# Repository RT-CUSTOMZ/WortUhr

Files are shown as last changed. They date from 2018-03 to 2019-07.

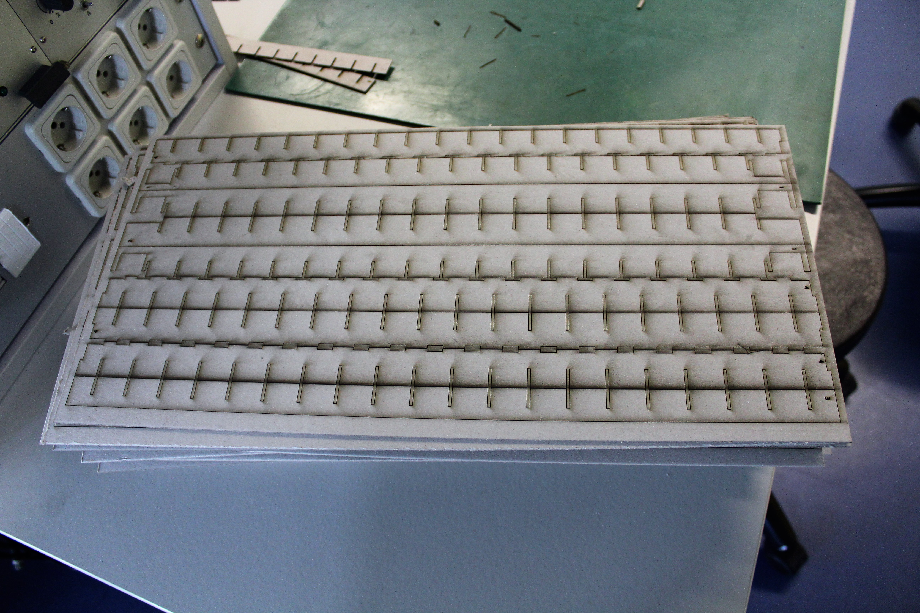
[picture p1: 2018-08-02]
Media/Gitterstreifen.jpg

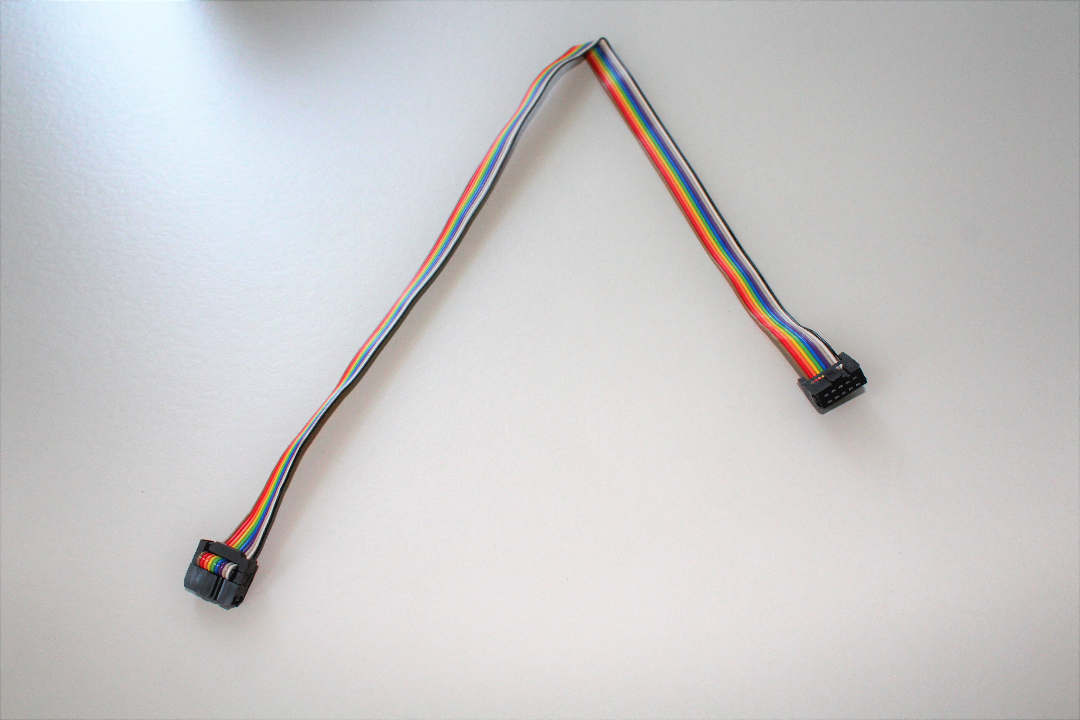
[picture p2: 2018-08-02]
Media/Flachbandkabel.jpg

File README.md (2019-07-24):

# Hardware
Im
Das Buchstabenlayout dieser WortUhr ist angelehnt an das Layout, welches von Frank Meyer verwendet wird.

# Software
Die Software von Frank Meyer wurde minimal angepasst. Das Layout der Matrix, sowie die Datenrichtung wurde angepasst.

Documentation: https://www.mikrocontroller.net/articles/WordClock_mit_WS2812

Version: 2.9.5

Copyright (c) 2014-2019 Frank Meyer - frank(at)fli4l.de

This program is free software; you can redistribute it and/or modify
it under the terms of the GNU General Public License as published by
the Free Software Foundation; either version 2 of the License, or
(at your option) any later version.

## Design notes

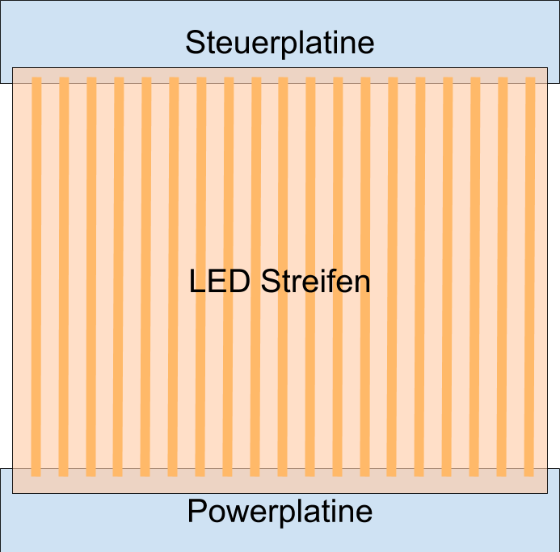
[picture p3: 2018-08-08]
Media/Struktur_Platinen.png

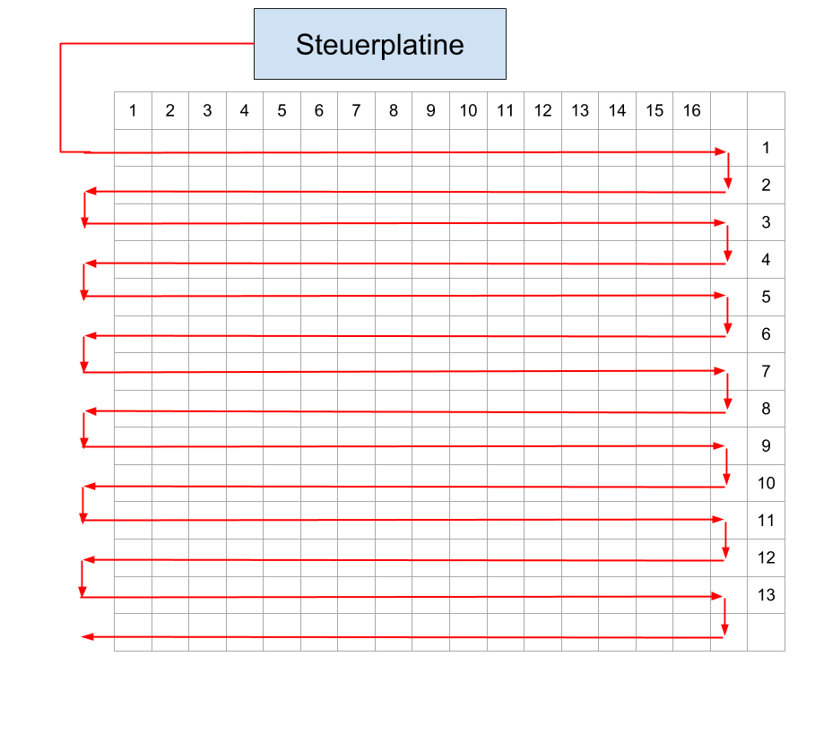
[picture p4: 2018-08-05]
Media/WortUhr alt.png

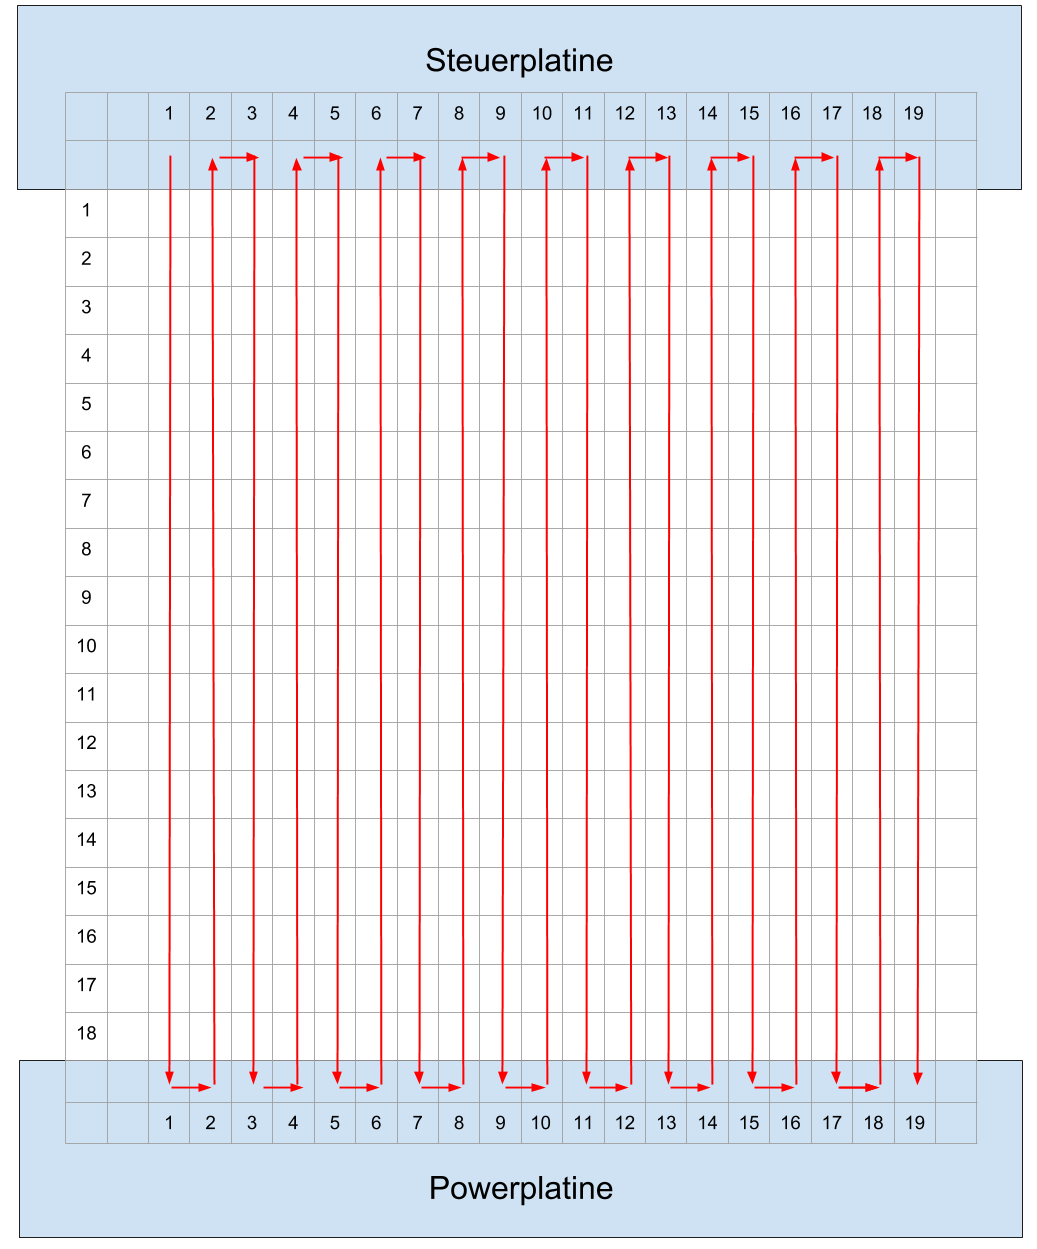
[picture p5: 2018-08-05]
Media/WortUhr neu.png

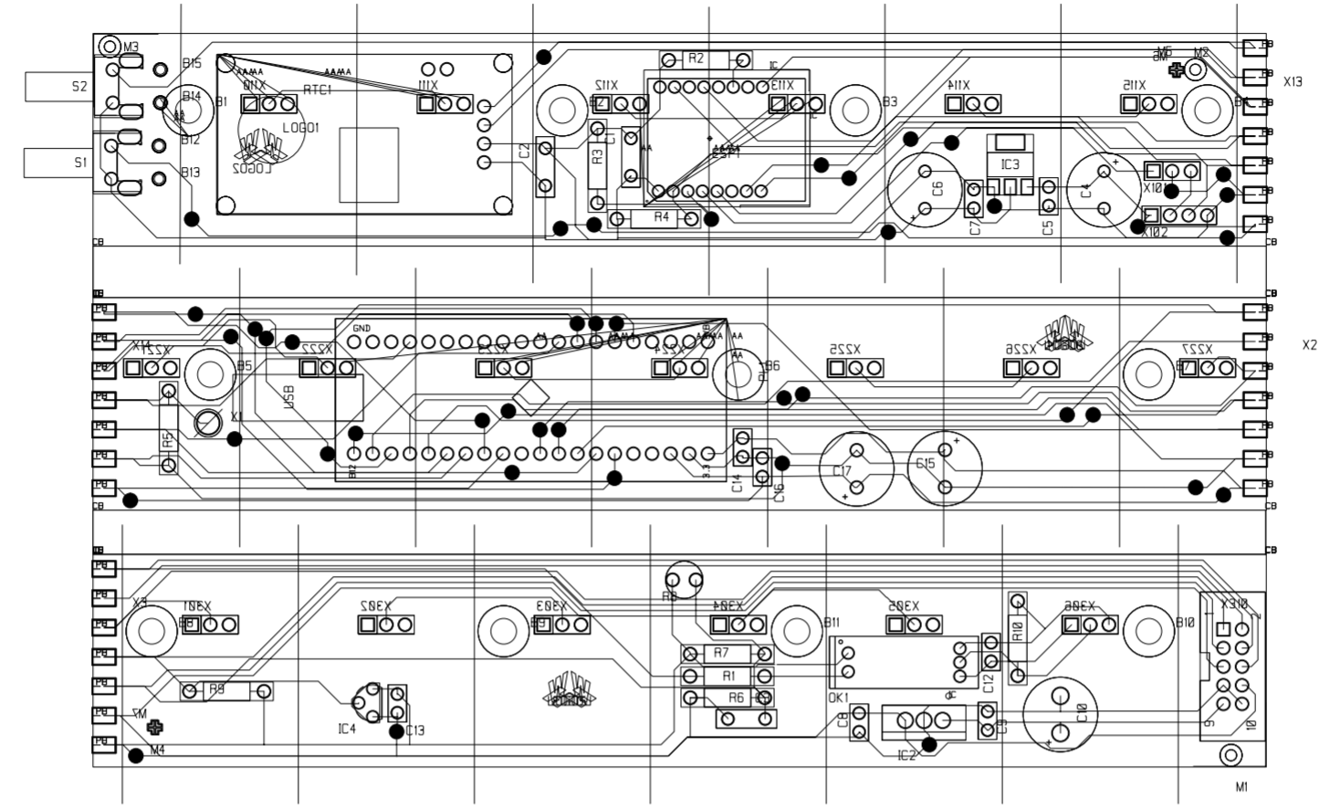
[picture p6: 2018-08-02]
Media/Steuerplatine - Viaplan.PNG

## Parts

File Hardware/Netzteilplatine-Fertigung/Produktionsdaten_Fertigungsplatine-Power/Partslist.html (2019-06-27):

CADSTAR Design Editor Version | 17.0.0.3
Design: | R:\Hardies\Wortuhr\Wortuhr_Netzteilplatine\Version V2.1\Fertigungsplatine_2.pcb
Design Title: | Wortuhr-Powerplatine_Version2.1-Kati
Date: | Donnerstag, 27. Juni 2019
Time: | 18:59
Part Name/Number | Description | Qty | Comps. | Part Acceptance
10_pol_wanne | Wannenstecker 10 pol | 1 | X101
4N36 | Optokoppler 2,5kV DIL6 7Âµs | 6 | OK11-12
 |  |  | OK21-22
 |  |  | OK31-32
Bohrung3_5 | Befestigungsbohrung 3,5mm | 10 | B1-10
ELKO_470µ_25V_RM5_RADIAL_D10MM | Elektrolytkondensator radial_D | 6 | C11-12
 |  |  | C21-22
 |  |  | C31-32
HEBW21 | HEBW21 | 1 | X102
IRF7425 | P-Kanal Mosfet | 3 | T11
 |  |  | T21
 |  |  | T31
LM2576 | LM2576 | 3 | IC1-3
LPKF_Passmarke | Platzhalter fuer Passmarke | 3 | M1-3
Loetoese | Lötöse | 3 | X1-3
PAD | Einzelnes Pad 1,5mm | 26 | X103-109
 |  |  | X203-209
 |  |  | X213-218
 |  |  | X313-318
PASTEN_PASSMARKE | Platzhalter fuer Passmarke | 4 | M4-7
Platzhalter | Platzhalter für Gehäuseauswahl | 1 | PCB1
RES_19K1_1.00%_0.40W_axial_Metallschicht_RT | Metallschichtwiderstand 19,1K | 6 | R15-16
 |  |  | R25-26
 |  |  | R35-36
RES_1K2_5.00%_0.25W_axial_Kohleschicht | Kohleschichtwiderstand 1,2k Oh | 3 | R11
 |  |  | R21
 |  |  | R31
RES_330R_5.00%_0.25W_AXIAL_KOHLESCHICHT_RT | Kohleschichtwiderstand 330 Ohm | 6 | R13-14
 |  |  | R23-24
 |  |  | R33-34
RES_3K9_5.00%_0.25W_axial_Kohleschicht | Kohleschichtwiderstand 3,9k Oh | 3 | R12
 |  |  | R22
 |  |  | R32
SPULE 100UH | Spule 100uH | 3 | L11
 |  |  | L21
 |  |  | L31
Steckerleiste_3pol | Steckerleiste SIL RM2,54 | 19 | X110-115
 |  |  | X221-227
 |  |  | X301-306
VS-30BQ100 | Schottky-Diode_SMD | 3 | D11
 |  |  | D21
 |  |  | D31
WHS_LOGO | Platzhalter für WHS Logo | 2 | LOGO1-2

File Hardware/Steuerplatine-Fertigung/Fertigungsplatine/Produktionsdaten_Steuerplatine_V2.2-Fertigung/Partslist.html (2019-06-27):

CADSTAR Design Editor Version | 17.0.0.3
Design: | R:\Hardies\Wortuhr\Wortuhr_Steuerplatine\Version 2.2\Fertigungsplatine\Fertigungsplatine_ Wortuhr_1.pcb
Design Title: | Wortuhr-Steuerplatine_Version_2.2-Kati
Date: | Donnerstag, 27. Juni 2019
Time: | 19:01
Part Name/Number | Description | Qty | Comps. | Part Acceptance
10_pol_wanne | Wannenstecker 10 pol | 1 | X31
7805_GESTEPPT | 7805_gesteppt | 1 | IC31
AMS1117 | Linearregler | 1 | IC10
Bohrung1_0 | Befestigungsbohrung 1,0mm | 4 | B13-16
Bohrung3_5 | Befestigungsbohrung 3,5mm | 8 | B1-8
CAP_100n_50V_RM5_L8mm_B2.5mm_Z5U_RT | Keramikkondensator L8mm_B2,5mm | 10 | C10-11
 |  |  | C13-14
 |  |  | C20-21
 |  |  | C30
 |  |  | C32-34
CAP_1n_50V_RM5_L4mm_B2mm_C0G_RT | Keramikkondensator L4mm_B2mm 1 | 3 | C22-23
 |  |  | C31
DS18B20 | Digital Thermometer, 1-wire | 1 | IC30
ELKO_10µ_63V_RM5_radial_D9mm | Elektrolytkondensator radial_D | 2 | C24-25
ELKO_330µ_35V_RM5_radial_D10mm | Elektrolytkondensator radial_D | 1 | C35
ELKO_47µ_63V_RM5_radial_D10mm | Elektrolytkondensator radial_D | 2 | C12
 |  |  | C15
ESP07 | ESP07 | 1 | ESP1
LDR | Fotowiderstand | 1 | R35
LPKF_Passmarke | Platzhalter fuer Passmarke | 4 | M1-2
 |  |  | M8-9
Loetoese | Lötöse | 3 | X10
 |  |  | X20
 |  |  | X30
PAD | Einzelnes Pad 1,5mm | 1 | X21
PASTEN_PASSMARKE | Platzhalter fuer Passmarke | 6 | M4-7
 |  |  | M10-11
RES_120R_5.00%_0.25W_axial_Kohleschicht_RT | Kohleschichtwiderstand 120 Ohm | 1 | R32
RES_240K_1.00%_0.40W_AXIAL_METALLSCHICHT_RT | Metallschichtwiderstand 240K O | 1 | R33
RES_4K53_1.00%_0.40W_axial_Metallschicht_RT | Metallschichtwiderstand 4,53K | 2 | R10-11
RES_8K2_5.00%_0.25W_axial_Kohleschicht_RT | Kohleschichtwiderstand 8,2k Oh | 5 | R12-14
 |  |  | R21
 |  |  | R30
RES_91R_1.00%_0.40W_axial_Metallschicht_RT | Metallschichtwiderstand 91 Ohm | 1 | R20
RES_nicht_bestückt_axial | Platzhalterwiderstand nicht be | 2 | R31
 |  |  | R34
RTC_DS3231_32K | RTC_DS3231_32K | 1 | RTC10
RT_LOGO | Platzhalter fuer RT Logo | 2 | LOGO7-8
SMD_STECKER_7_12 | SMD Loetbruecke | 2 | X14
 |  |  | X132
SMD_Stecker_7_23 | SMD Loetbruecke | 2 | X2-3
STM32-einfach | Tochterplatine STM32 | 1 | PL20
Steckerleiste_2pol | Steckerleiste SIL RM2,54 | 1 | X11
Steckerleiste_3pol | Steckerleiste SIL RM2,54 | 20 | X12
 |  |  | X110-115
 |  |  | X221-227
 |  |  | X301-306
Steckerleiste_4pol | Steckerleiste SIL RM2,54 | 1 | X13
TLP582 | Optokoppler 5kV Schmitt Trigge | 1 | OK31
Taster3305 | Kurzhubtaster PHAP3305D | 2 | S10-11
WHS_LOGO | Platzhalter für WHS Logo | 4 | LOGO3-6

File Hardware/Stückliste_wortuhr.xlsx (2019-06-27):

Stk.: | Bezeichnung: | Firma: | Best. Nr.: | Seite: | Netto: | Brutto: | Rabatt: | Preis/Stk: | Gesamt: | Arbeitsschritt | Bauteilbezeichnung: | Bestand:
Steuerplatine
1 | RES_120R_5.00%_0.25W_axial_Kohleschicht_RT |  |  |  | 0.00 € | 0.00 € |  | 0.00 € | 0.00 € | 1 | R32 | RT
5 | RES_8K2_5.00%_0.25W_axial_Kohleschicht_RT |  |  |  | 0.00 € | 0.00 € |  | 0.00 € | 0.00 € | 2 | R12-14, R21, R30 | RT
2 | 4K53Ohm |  |  |  |  |  |  |  |  | 3 | R10-11 | RT
1 | 100Ohm |  |  |  |  |  |  |  |  | 4 | R20
1 | RES_240K_1.00%_0.40W_AXIAL_METALLSCHICHT_RT |  |  |  | 0.00 € | 0.00 € |  | 0.00 € | 0.00 € | 5 | R33 | RT
1 | AMS1117-Linearregler | reichelt | LM 1117 MP5,0 |  | 0.72 € | 0.86 € |  | 0.86 € | 0.86 € | 6 | IC10 | 57
1 | 2pol Steckerleiste RM2.54 | reichelt | SL1X36G2,54 |  | 0.14 € | 0.17 € |  | 0.17 € | 0.17 € | 7
1 | 3pol Stiftleiste Rm2,54 | reichelt | SL1X36G2,54 |  | 0.14 € | 0.17 € |  | 0.17 € | 0.17 € | 8 | X12 | 36pol:56
2 | 4pol Stiftleiste RM2,54 | reichelt | SL1X36G2,54 |  | 0.14 € | 0.17 € |  | 0.17 € | 0.34 € | 9 | X13, RTC | s.o.
2 | 8pol Stiftleiste RM2 | reichelt | SL1X32G2,00 |  | 0.21 € | 0.25 € |  | 0.25 € | 0.50 € | 10 | ESP | 32pol:37
10 | CAP_100n_50V_RM5_L8mm_B2.5mm_X7R | reichelt | C3X7R 100NB50 |  | 0.08 € | 0.10 € |  | 0.10 € | 1.00 € | 11 | C10-11, C13-14, C20-21, C30, C32-34 | 12
3 | CAP_1n_50V_RM5_L4mm_B2mm_C0G_RT |  |  |  | 0.00 € | 0.00 € |  | 0.00 € | 0.00 € | 12 | C22-23, C31 | RT
1 | Temperatursensor | reichelt | DS18B20 |  | 1.51 € | 1.80 € |  | 1.80 € | 1.80 € | 13 | IC30 | 11
1 | LDR | RS | 914-6710 |  | 0.71 € | 0.84 € |  | 0.84 € | 0.84 € | 14 | R35 | 46
2 | Taster 3301D | reichelt | TASTER 3301D |  | 0.11 € | 0.13 € |  | 0.13 € | 0.26 € | 15 | S10-11 | 8
1 | 7805 Spannungsregler 5V TO220 gesteppt | reichelt | R-78 E50-05 |  | 2.77 € | 3.30 € |  | 3.30 € | 3.30 € | 16 | IC31 | 3
1 | TLP582 Optokoppler 5kV Schmitt Trigge_RT |  |  |  | 0.00 € | 0.00 € |  | 0.00 € | 0.00 € | 17 | OK31 | RT
2 | ELKO_47µ_63V_RM5_radial_D10mm | RS | 771-1586 |  | 0.08 € | 0.09 € |  | 0.09 € | 0.19 € | 18 | C24-25 | 39
1 | ELKO_330µ_35V_RM5_radial_D10mm | reichelt | RAD 330/35 |  | 0.07 € | 0.08 € |  | 0.08 € | 0.08 € | 19 | C35 | 18
2 | ELKO_10µ_63V_RM5_radial_D9mm | reichelt | RAD 10/63 |  | 0.02 € | 0.02 € |  | 0.02 € | 0.04 € | 20 | C12, C15 | 38
1 | 10_pol_wanne | reichelt | WSL 10G |  | 0.08 € | 0.10 € |  | 0.10 € | 0.10 € | 21 | X31 | 4
 |  |  |  |  |  | 0.00 € |  | 0.00 €
 |  |  |  |  |  | 0.00 € |  | 0.00 €
1 | RTC_DS3231 | eckstein | CP14004 |  | 0.00 € | 3.86 |  | 3.86 € | 3.86 € | 22 | RTC1 | 36
2 | M2 Schrauben 16mm | reichelt | SZK M2X16-200 |  | 1.85 € | 2.20 € |  | 2.20 € | 4.40 € | 23 | M2 Schrauben | 200
2 | M2 Muttern | reichelt | SK M2-1000 |  | 9.20 € | 10.95 € |  | 10.95 € | 21.90 € | 24 | M2 Muttern | 45
2 | Abstandsbolzen |  |  |  | 0.00 € | 0.00 € |  | 0.00 € | 0.00 € | 25 |  | 100
1 | ESP07 | wetterott | 20150271 |  | 0.00 € | 3.85 € |  | 3.85 € | 3.85 € | 26 | ESP1 | 29
2 | Sockelleisten 1X32 RM 2 | reichelt | BL1X32G 2,00 |  | 0.68 € | 0.81 € |  | 0.81 € | 1.62 € | 27 | 8pol RM2 | 11
1 | STM32 F103C8T6 | ebay |  |  | 0.00 € | 4.49 € |  | 4.49 € | 4.49 € | 28 | PL1 | 0
2 | Sockelleisten 1x20 RM2,54 | reichelt | BL 1X20G 2,54 |  | 0.61 € | 0.73 € |  | 0.73 € | 1.45 € | 29 | 20pol RM2,54 | 100
19 | gewinkelte Steckerleiste3 pol RM2,54 |  | BL 1X20W8 2,54 |  | 0.38 € | 0.45 € |  | 0.45 € | 8.59 € | 30 | X110-115, X221-227;x301-306 | 53
3 | Lötöse |  |  |  |  | 0.00 € |  | 0.00 € | 0.00 € | 40 | X10, X20, X30
 |  |  |  |  |  | 0.00 € |  | 0.00 € | 0.00 €
Zubehör |  |  |  |  |  | 0.00 € |  | 0.00 €
2 | 10 pol Pfostenbuchse | reichelt | PFL 10 |  | 0.08 € | 0.10 € |  | 0.10 € | 0.20 € |  |  | 1
1 | Flachbandkabel | reichelt | AWG28-10F 3M |  | 1.67 € | 1.99 € |  | 1.99 € | 1.99 €
342 | LED´s |  |  |  |  | 0.00 € |  | 0.00 € | 0.00 € |  |  | 4,75 Rollen |  | 11 Rollen
0,25 Rollen | Silberdrath | Bürklin | 90F272 |  | 37.60 € | 44.74 € |  | 44.74 € | #VALUE! |  |  | 5 mit CUBE! |  | n
1 | Bilderrahmen | Ikea | 003.784.36 |  |  | 12.99 € |  |  |  |  |  | 9 | 12
1 | Folie
24 | M3 Schrauben |  |  |  |  | 0.00 € |  | 0.00 € | 0.00 €
24 | M3 Muttern
24 | M3 Unterlegschreiben |  |  |  |  |  |  |  |  |  |  |  | 500
5cm | schrumpfschlauch 1,6mm |  |  |  |  |  |  |  |  | 14
Powerplatine |  |  |  |  |  | 0.00 € |  | 0.00 €
 |  |  |  |  |  | 0.00 € |  | 0.00 € | 0.00 €
19 | gewinkelte Steckerleiste3 pol RM2,54 |  | BL 1X20W8 2,54 |  | 0.38 € | 0.45 € |  | 0.45 € | 8.59 € | 41 | X110-115, C221-227, X301-306
12 | Sockelleisten 3pol RM2,54 |  |  |  |  | 0.00 € |  | 0.00 € | 0.00 € | 42 | OK11-12, OK21-22, OK31-32
3 | P-Ch FET IRF7425 | reichelt | IRF7425 |  | 0.78 | 0.93 € |  | 0.93 € | 2.78 € | 43 | T11, T21, T31
6 | Widerstand 19,1K RT |  |  |  |  | 0.00 € |  | 0.00 € | 0.00 € | 44 | R15-16, R25-26, R36-36 | RT
3 | Widerstand 1,2K | aliexpress |  |  |  |  |  | 0.00 € | 0.00 € | 45 | R11, R21, R31
6 | Widerstand 330R RT |  |  |  |  | 0.00 € |  | 0.00 € | 0.00 € | 46 | R13-14, R23-24, R33-34 | RT
3 | Widerstand 3,9K | aliexpress |  |  |  | 0.00 € |  | 0.00 € | 0.00 € | 47 | R12, R22, R32
3 | SMD Diode Shottky: VS-30BQ100 | farnell | 2628291 |  |  | 0.00 € |  | 0.00 € | 0.00 € | 48 | D11, D21, D31
3 | LM2576 S-ADJ | reichelt | LM 2576 S-ADJ |  | 1.51 | 1.80 € |  | 1.80 € | 5.39 € | 49 | IC1-3
3 | Spule 100uH | reichelt | L-PISR 100µ |  | 0.75 | 0.89 € |  | 0.89 € | 2.68 € | 50 | L11, L21, L31
1 | Wannenstecker 10Pol | reichelt | WSL 10G |  | 0.08 € | 0.10 € |  | 0.10 € | 0.10 € | 51 | X101
6 | Elko 470uF 25V | aliexpress |  |  |  | 0.00 € |  | 0.00 € | 0.00 € | 52 | C11-12, C21-22, C31-32
1 | Holsteckerbuchse | reichelt | LUM NEB 21R |  | 0.40 € | 0.48 € |  | 0.48 € | 0.48 € | 53 | X102
6 | Optokoppler 4N36 | reichelt | 4N36 |  | 0.22 | 0.26 € |  | 0.26 € | 1.57 € | 54 | OK11-12, OK21-22, OK31-32
3 | Lötöse |  |  |  |  |  |  |  |  | 55 | X1-3
 |  |  |  |  |  |  |  |  | #VALUE!

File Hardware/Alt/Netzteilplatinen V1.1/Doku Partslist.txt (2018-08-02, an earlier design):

<!DOCTYPE HTML PUBLIC "-//W3C//DTD HTML 4.01 Transitional//EN" "http://www.w3.org/TR/html4/loose.dtd"><HTML>
<HEAD>
<META NAME="GENERATOR" CONTENT="Cadstar Active Report">
<META NAME="AUTHOR" CONTENT="Zuken Ltd">
<TITLE>Parts List</TITLE>
<style type="text/css">/* CADSTAR HTML Reports CSS File V1.2 SL 08-Jul-2015 */

body
{
	font-family:'Lucida Sans Unicode', 'Lucida Grande', Sans-Serif;
	font-size:x-small;
	background:#FFF;
	color:#101010;
	margin-left:22px;
}

pre
{
    font-family:'Lucida Sans Unicode', 'Lucida Grande', Sans-Serif;
	font-size:x-small
} 

hr
{
	margin-right:22px;
    height:1px;
} 

td.number-col
{
	text-align:right
} 

ul
{
	margin-left:3em;
	padding-left:0;
} 

li
{	
	line-height:1.8em
} 

.label-for-check
{
	text-decoration:underline
}

.check-with-label:checked + .label-for-check
{
	color:#F01010
} 

a
{
	color:#000
} 

.hor-header-summary-a
{
    font-family:'Lucida Sans Unicode', 'Lucida Grande', Sans-Serif;
	font-size:1em;
    background:#FFF;
	margin-bottom:2em;
	margin-top:1em
} 

.hor-header-summary-a th
{
	font-size:14px;
	font-weight:400;
	border-bottom:2px solid #6678b1;
	padding:10px 24px
} 

.hor-header-summary-a td
{
	color:#101010;
	vertical-align:baseline;
	padding:9px 24px 0 0
}

.hor-header-summary-a tbody td
{
	color:#101010
} 

#content tr:hover 
{
    background: #FAFAFA;
} 

.hor-minimalist-a
{
    font-family:'Lucida Sans Unicode', 'Lucida Grande', Sans-Serif;
	font-size:x-small;
	background:#fff;
	margin-bottom:3em;
	#margin-top:3em;
	border-collapse:collapse;
	text-align:left;
	line-height:1em
}

.hor-minimalist-a td
{
	padding:9px 48px 0 0
} 

table
{
	margin-top:0;padding-top:0
} 

h1,h2,h3
{
	margin-bottom:0;
	padding-bottom:0
} 

h1
{
	font-size:1.5em
} 

h3,h4
{
	font-size:1.2em
} 

.hor-header-summary-a thead,.hor-minimalist-a thead
{
	color:#101010;
	font-weight:700;
	padding:10px 24px
} 

.ActiveLink 
{
	color:#000000
} 

.ActiveLinkDRC 
{
	color:#0000FF
} 

.ActiveLinkSelected 
{
	color:#000000; 
	background-color:#B0ffB0;
} 

.ActiveLinkDRCSelected 
{
	color:#0000FF; 
	background-color:#B0ffB0;
} 

pre
{
	display: inline
}

.altTable 
{
	font-size:1em;
	margin-bottom:2em;
	margin-top:1em;
	border-collapse:
	collapse;text-align:left
}

.altTable th
{
	font-size:14px;
	font-weight:500;
	border-bottom:2px;
	padding:2px 5px 5px
} 

.altTable td
{
	color:#101010;
	vertical-align:top;
	padding:1px 6px
}
</style>
</HEAD>
<body>
<H1>
Parts List
</H1>
<table class="hor-header-summary-a">
<tr><td>CADSTAR Design Editor Version</td><td>17.0.0.3</td></tr>
<tr><td>Design:</td><td>R:\TEMP\Wortuhr-Netzteilplatine -Nutzen 1,1-BO.pcb</td></tr>

<tr>

<td>
Design Title:
</td>

<td>
<pre>
WortUhr Powerplatine Nutzen</pre>

</td>

</tr>
<tr><td>Date:</td><td>Samstag, 28. Juli 2018</td></tr>
<tr><td>Time:</td><td>14:34</td></tr>

</table>
<hr>
<div id="content"><table class="hor-header-summary-a">

<thead>

<tr>

<td>
Part Name/Number       
</td>

<td>
Description
</td>

<td>
Qty
</td>

<td>
   Comps.
</td>

<td>
Part Acceptance
</td>

</tr>

</thead>

<tr>

<td>
10_pol_wanne
</td>

<td>
Wannenstecker 10 pol
</td>

<td class="number-col">
1
</td>

<td>
X101
</td>

</tr>

<tr>

<td>
1N5408
</td>

<td>
Silizium Diode
</td>

<td class="number-col">
3
</td>

<td>
D11
</td>

</tr>

<tr>

<td>

</td>

<td>

</td>

<td>

</td>

<td>
D21
</td>

</tr>

<tr>

<td>

</td>

<td>

</td>

<td>

</td>

<td>
D31
</td>

</tr>

<tr>

<td>
4N36
</td>

<td>
Optokoppler 2,5kV DIL6 7Âµs
</td>

<td class="number-col">
6
</td>

<td>
OK11-12
</td>

</tr>

<tr>

<td>

</td>

<td>

</td>

<td>

</td>

<td>
OK21-22
</td>

</tr>

<tr>

<td>

</td>

<td>

</td>

<td>

</td>

<td>
OK31-32
</td>

</tr>

<tr>

<td>
Bohrung3_5
</td>

<td>
Befestigungsbohrung 3,5mm
</td>

<td class="number-col">
11
</td>

<td>
B1-11
</td>

</tr>

<tr>

<td>
ELKO_1000µ_50V_RM5_radial_D13mm_RT
</td>

<td>
Elektrolytkondensator radial_D
</td>

<td class="number-col">
6
</td>

<td>
C11-12
</td>

</tr>

<tr>

<td>

</td>

<td>

</td>

<td>

</td>

<td>
C21-22
</td>

</tr>

<tr>

<td>

</td>

<td>

</td>

<td>

</td>

<td>
C31-32
</td>

</tr>

<tr>

<td>
Hohlsteckerbuchse_HEBW21
</td>

<td>
Hohlsteckerbuchse_2,1*5,5mm
</td>

<td class="number-col">
1
</td>

<td>
X102
</td>

</tr>

<tr>

<td>
IRF7425
</td>

<td>
IRF7425
</td>

<td class="number-col">
3
</td>

<td>
T11
</td>

</tr>

<tr>

<td>

</td>

<td>

</td>

<td>

</td>

<td>
T21
</td>

</tr>

<tr>

<td>

</td>

<td>

</td>

<td>

</td>

<td>
T31
</td>

</tr>

<tr>

<td>
LPKF_Passmarke
</td>

<td>
Platzhalter fuer Passmarke
</td>

<td class="number-col">
3
</td>

<td>
M1-3
</td>

</tr>

<tr>

<td>
PAD
</td>

<td>
Einzelnes Pad 1,5mm
</td>

<td class="number-col">
26
</td>

<td>
X103-109
</td>

</tr>

<tr>

<td>

</td>

<td>

</td>

<td>

</td>

<td>
X203-209
</td>

</tr>

<tr>

<td>

</td>

<td>

</td>

<td>

</td>

<td>
X213-218
</td>

</tr>

<tr>

<td>

</td>

<td>

</td>

<td>

</td>

<td>
X313-318
</td>

</tr>

<tr>

<td>
PASTEN_PASSMARKE
</td>

<td>
Platzhalter fuer Passmarke
</td>

<td class="number-col">
4
</td>

<td>
M4-7
</td>

</tr>

<tr>

<td>
RES_19K1_1.00%_0.40W_axial_Metallschicht_RT
</td>

<td>
Metallschichtwiderstand 19,1K 
</td>

<td class="number-col">
6
</td>

<td>
R15-16
</td>

</tr>

<tr>

<td>

</td>

<td>

</td>

<td>

</td>

<td>
R25-26
</td>

</tr>

<tr>

<td>

</td>

<td>

</td>

<td>

</td>

<td>
R35-36
</td>

</tr>

<tr>

<td>
RES_1K2_5.00%_0.25W_axial_Kohleschicht
</td>

<td>
Kohleschichtwiderstand 1,2k Oh
</td>

<td class="number-col">
3
</td>

<td>
R11
</td>

</tr>

<tr>

<td>

</td>

<td>

</td>

<td>

</td>

<td>
R21
</td>

</tr>

<tr>

<td>

</td>

<td>

</td>

<td>

</td>

<td>
R31
</td>

</tr>

<tr>

<td>
RES_330R_5.00%_0.25W_AXIAL_KOHLESCHICHT_RT
</td>

<td>
Kohleschichtwiderstand 330 Ohm
</td>

<td class="number-col">
6
</td>

<td>
R13-14
</td>

</tr>

<tr>

<td>

</td>

<td>

</td>

<td>

</td>

<td>
R23-24
</td>

</tr>

<tr>

<td>

</td>

<td>

</td>

<td>

</td>

<td>
R33-34
</td>

</tr>

<tr>

<td>
RES_3K9_5.00%_0.25W_axial_Kohleschicht
</td>

<td>
Kohleschichtwiderstand 3,9k Oh
</td>

<td class="number-col">
3
</td>

<td>
R12
</td>

</tr>

<tr>

<td>

</td>

<td>

</td>

<td>

</td>

<td>
R22
</td>

</tr>

<tr>

<td>

</td>

<td>

</td>

<td>

</td>

<td>
R32
</td>

</tr>

<tr>

<td>
Spule 470uH
</td>

<td>
Spule 470uH
</td>

<td class="number-col">
3
</td>

<td>
L11
</td>

</tr>

<tr>

<td>

</td>

<td>

</td>

<td>

</td>

<td>
L21
</td>

</tr>

<tr>

<td>

</td>

<td>

</td>

<td>

</td>

<td>
L31
</td>

</tr>

<tr>

<td>
Steckerleiste_3pol
</td>

<td>
Steckerleiste SIL RM2,54
</td>

<td class="number-col">
19
</td>

<td>
X110-115
</td>

</tr>

<tr>

<td>

</td>

<td>

</td>

<td>

</td>

<td>
X221-227
</td>

</tr>

<tr>

<td>

</td>

<td>

</td>

<td>

</td>

<td>
X301-306
</td>

</tr>

<tr>

<td>
TL2575
</td>

<td>
Schaltregler
</td>

<td class="number-col">
3
</td>

<td>
IC11
</td>

</tr>

<tr>

<td>

</td>

<td>

</td>

<td>

</td>

<td>
IC21
</td>

</tr>

<tr>

<td>

</td>

<td>

</td>

<td>

</td>

<td>
IC31
</td>

</tr>

<tr>

<td>
WHS_LOGO
</td>

<td>
Platzhalter für WHS Logo
</td>

<td class="number-col">
2
</td>

<td>
LOGO1-2
</td>

</tr>

</table>
</div><BR>
<BR>
End of report

</body>
</html>

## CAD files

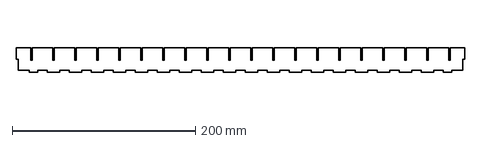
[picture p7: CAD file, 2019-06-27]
Lasercutter/Gitter_4.dxf
489.0 x 26.5 mm

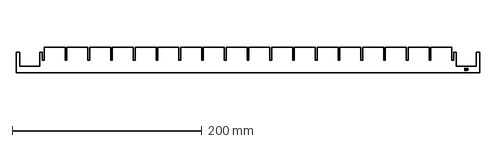
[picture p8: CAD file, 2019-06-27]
Lasercutter/Gitter_2.dxf
489.0 x 26.5 mm

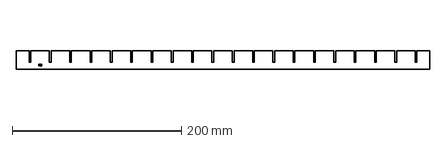
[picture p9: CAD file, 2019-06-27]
Lasercutter/Gitter_3.dxf
489.0 x 21.5 mm

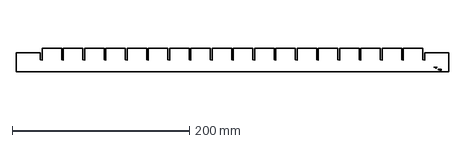
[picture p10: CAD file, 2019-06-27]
Lasercutter/Gitter_1.dxf
489.0 x 26.5 mm

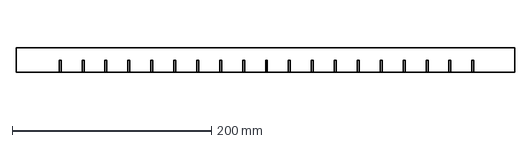
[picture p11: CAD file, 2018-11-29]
Lasercutter/Gitter_Horizontal.dxf
500.0 x 25.0 mm

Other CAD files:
Lasercutter/Gitter.dxf
Lasercutter/Gitter_Vertikal.dxf

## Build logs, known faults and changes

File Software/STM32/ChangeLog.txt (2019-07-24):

STM32 Version 2.9.4:

   - Neues Spiel: Snake
   - Bugfix: Marker-Colors wurden nicht mehr berücksichtigt, wenn "Sync Display Colors" für Ambilight eingestellt war.
   - Bugfix: Mitternachtsberechnung (nur relevant für französisches WC12-Layout)

STM32 Version 2.9.3:

   - Diverse Bugfixes in der Ambilight-Helligkeitsberechnung

STM32 Version 2.9.2:

   - Fading der Ambilight-LEDs im Clock- & Clock2-Modus ein- und ausschaltbar
   - Marker Colors in der Clock-Animation: Zusätzliche Einstellung "Use Display Colors"
   - Optimierung der SK6812-Timings für längere Zuleitungen
   - WC12h: Fading der Minutenpunkte
   - Umstellung der Wettervorhersage von Tages-Vorhersage ("daily forecast") auf 24h-Vorhersage ("hour forecast")
   - Bugfix Timer: Display schaltet sich erst beim nächsten Overlay ein

STM32 Version 2.9.1:

   - Bugfix: Makefile: STM32F4xx-Varianten (2.9.0) waren nicht lauffähig.
   - Bugfix: Berücksichtigung des Weiß-Kanals der SK6812 für Clock & Clock2
   - Logging des Boot-Vorgangs ausführlicher
   - Standard-Werte für Ambilight-Brightness auf lineare Werte 0-15 gesetzt.

STM32 Version 2.9.0:

   - Neu: Auslagerung der Display-Layouts in das SPIFFS des ESP8266.
   - Neu: Hochladen eigener Display-Layouts über das Webinterface möglich.
   - Neu: Ambilight Modes "CLOCK" und "CLOCK2": beliebige Anzahl von Ambilight-LEDs möglich.
   - Neu: Ambilight Mode Clock: Farbe der 5-Sekunden-Marker einstellbar.
   - Neu: Ambilight Mode Clock und Clock2: Fading der Ambilight-LEDs
   - Neu: Ambilight-Helligkeitskurve.
   - Neu: Icons in Overlays: Gezieltes Ausblenden von LEDs.
   - Neu: Angabe eines Ausgabeformats für die Ticker-Datumsanzeige.
   - Neu: Zusätzlicher Ambilight-Timer.
   - Neu: Animation "Matrix" in aktueller Displayfarbe, bisherige Matrix-Animation: "GreenMatrix".
   - Neu: Snake Animation: Schlange baut nun die neue Uhrzeit gleichzeitig wieder hinter sich auf.
   - Neu: Display-Modus "Tirol": Anzeige von DREIVIERTEL um hh:45, jedoch VIERTEL NACH um hh:15 - wie Rhein/Ruhr.
   - Neu: Display-Modus "Jester" (1. April): Unorthodoxe Anzeige für den 1. April oder andere Anlässe.
   - Neu: Color- bzw. Ambilight-Animation "Daylight": gesteuert nach Uhrzeit (von morgens rot nach abends blau)
   - Neu: Wetter: Unterscheidung aktuelles Wetter und Vorhersage - auch in den Overlays (FC = Forecast = Vorhersage).
   - Neu: Wetterticker: Temperaturwerte werden nun gerundet.
   - Neu: Webinterface: Neuer Button "Reset EEPROM" im Hauptmenü.
   - Neu: Webinterface: Neuer Button "Reset STM32" im Hauptmenü - funktioniert nur mit ESP-12F.
   - Bugfix: LDR-Startwerte für MIN und MAX auf sinnvolle Werte geändert.
   - Bugfix: Ende-Kennung von DFPLayer mit Firmware 0008 statt 0005.

STM32 Version 2.8.4:

   - Bugfix: Icons wurden bei aktivierter Helligkeitsanpassung teilweise nach sehr kurzer Zeit wieder ausgeblendet.

STM32 Version 2.8.3:

   - Bugfix: Daten für openweather.org wurden beim Boot versehentlich gelöscht, wenn LON & LAT leer sind.

STM32 Version 2.8.2:

   - Neues Overlay "DFPlayer": Abspielen von MP3-Dateien.
   - Overlays: Display-Button wieder eingebaut.
   - WordClock24h: Countdown-Modus vervollständigt für Silvester.
   - DCF77-Empfang wird nun abgeschaltet, solange das Display eingeschaltet ist.
   - Daten für openweather.org werden bei nicht-initialisierten EEPROM-Speicherbereichen auf 0 zurückgesetzt.

STM32 Version 2.8.1:

   - Timer-Tabellen werden nun auf 0 zurückgesetzt bei nicht-initialisierten EEPROM-Speicherbereichen.
   - Kommunikationsprobleme zwischen ESP8266 und STM32 bei automatischer Helligkeitsregelung beseitigt.
   - Änderungen der Brightness Tabellen wirken sich nun unmittelbar auf die Anzeige aus.
   - Automatische Helligkeitsregelung: Sprünge bei der Raumhelligkeit werden nun weich angepasst.

STM32 Version 2.8.0:

   - Neue Konfigurationsseiten im Webinterface: Overlays und SPIFFS
   - Neu: Datumsabhängiges Einblenden von Overlays
   - Neu: Einbindung von Wetter-Icons als Overlays
   - Neu: Ticker-Text als Overlay
   - Neu: Wetter-Ticker als Overlay
   - Neu: Geänderte Menüanordnung der Weboberfläche
   - Neu: Rotes Flackern der Status-LED bzw. der Minuten-LEDs beim Upgrade der EEPROM-Version
   - Auslagerung der Overlay-Icons ins SPIFFS des ESP8266
   - Diverse Optimierungen zwecks Einsparung von Flash
   - Einige kleinere Bugfixes
   - Neue Sprachvarianten für WC12h: Französisch und Schwedisch

STM32 Version 2.7.3:

   - Neu: Web-Interface: Abspielen eines Tracks per Button "Play".
   - Neu: Neue API-Funktion über UDP: Abspielen eines Tracks.
   - Neu: Einblenden eines Overlays per Button "Display".
   - Neu: Neue API-Funktion über UDP: Einblenden eines Overlays.
   - Bugfix: Im Bell-Modus wurden die Tracks zu jeder Viertelstunde unabhängig zur Einstellung abgespielt.

STM32 Version 2.7.2:

   - WC12h: Korrektur Englisch-Layout: Wort PAST fehlte um xx:30 Uhr.
   - NEU: Reset des I2C-Bus, wenn EEPROM und RTC nicht erkannt werden.
   - Bugfix: Wetterdaten wurden nicht mehr angezeigt.

STM32 Version 2.7.0:

   - Neu: Abspielen von MP3-Tracks über Mini DFPlayer bei ausgewählten Ereignissen.
   - Neu: Sprechende Uhr.
   - Neu: Bis zu acht Weckzeiten konfigurierbar.
   - Neu: Advent (1-4) Overlays.
   - Bugfix Timer-Tabellen: Bei gleichem Wochentag wurde der Timer nicht erkannt.
   - Bugfix: Schweizerdeutsch-Layouts (WC12h)
   - Bugfix: Board-LED leuchtet nun wieder, wenn ESP8266 über STM32 geflasht wird.
   - Takt des STM32F411RE von 84MHz auf 100MHz erhöht.
   - Webinterface: Neu: Power-Status Anzeige
   - Webinterface: Neu: DFPlayer-Status-Anzeige
   - Webinterface: Neu: Formatieren des ESP8266-SPIFFS Dateisystems
   - ESP8266: Mehrere Bugfixes und mehr Fehlerbehandlungen im Source-Code.
   - Vorbereitung Unterstützung der Interpretersprache NIC.
   - Neu: Unterstützung für Nucleo STM32F446RE eingebaut - ungetestet.

STM32 Version 2.6.7:

   - Schweizerdeutsch-Layouts: Ausgabe vereinfacht (ohne "UHR").

STM32 Version 2.6.6:

   - Anzahl der möglichen Ambilight-LEDs einheitlich auf 120 erhöht.
   - Bugfix: Ermittlung der Hardware-Konfiguration für HEX-Datei-Vorschlag beim OTA-Update korrigiert.
   - Maximal möglichen Wert für Ticker-Verögerung ("Deceleration") auf 16 beschränkt.
   - Bugfix I2C-Treiber (betrifft RTC & EEPROM): Busy-Condition nach StopBit-Generierung wurde bisher nicht beachtet.
   - Plausibilitäts-Tests auf EEPROM-Werte verbessert.

STM32 Version 2.6.5:

   - Optimierung: Double-Buffering für SK6812-DMA-Transfer - analog zu WS2812 in Version 2.6.4.
   - Bugfix: Update von undefinierten EEPROM-Inhalten, welche in 2.6.x zu Hangups führen konnten.
   - Bugfix: Nach Spielen von Tetris wurde nicht immer die aktuelle Uhrzeit wieder eingeblendet.

STM32 Version 2.6.4:

   - Verlängerung der Pausen für WS2812 auf 300us.
   - Verschäfte Plausibilitätsprüfungen für EEPROM-Inhalte, ggfls. RESET auf Standardwerte.

STM32 Version 2.6.3:

   - Bugfix: Flackern bzw. versetztes Ausgabe der Display-LEDs durch Double-Buffering behoben.

STM32 Version 2.6.2:

   - Änderung: 5-Sekunden-Marker für Ambilight-Modus "Clock" ist nun ein-/abschaltbar.

STM32 Version 2.6.1:

   - Bugfix: Ein-/Ausschalten des Ambilights inkl. Timer.
   - Bugfix: Das aktuelle Datum/Uhrzeit wurde im Webinterface nicht angezeigt.
   - Änderung: Schweizerdeutsch 2: Auch zur vollen Stunde wird nun die Anzeige von "UHR" unterdrückt.

STM32 Version 2.6.0:

   - Neu: WPS Button, damit ESP8266 sich per WPS mit dem Router (AccessPoint) verbinden kann.
   - Neu: Liste der verfügbaren Access-Points im Webinterface.
   - Neu: Abschaltbares Ambilight per WebInterface - ungetestet.
   - Neu: Ein-/Ausschalten des Ambilights über Timer - ungetestet.
   - Neu: Ambilight-Animation "Clock" jetzt mit 5-Sekunden-Marker - ungetestet.
   - Neu: Konfigurierbare Helligkeitskurve bei automatischer oder manueller Regelung.
   - Neu: Geschwindigkeitsregelung der Ticker-Texte
   - Neu: OTA-Update des STM32 nun auch mit Upload vom lokalen PC aus möglich.
   - Neu: Konfigurierbarer Host und Pfad für OTA-Updates - geplant für die zukünftige Herausgabe von Pre-Testversionen im neuen Pfad "test".
   - Optimierung der DS18xx/OneWire/Delay-Funktionen, um die Prozessorlast zu minimieren.
   - Bugfix: Falsche Berechnung von Überläufen in CLOCK2-Animation für Ambilight (Anzahl Ambilight-LEDs = 30) korrigiert.
   - Bugfix: Diverse Korrekturen im Layout English2 für WC12h.
   - Neu: Zusätzliches Layout für WC12h: "Schweizerdeutsch 2".
   - Neu: WCtris, noch ein Tetris-Clone. Bedienbar über die Android-App.
   - Änderung der Verbindung zwischen ESP-12F und STM32: GPIO4 (und nicht mehr GPIO16) muss nun mit BOOT0 des STM32 verbunden werden
   - Umstellung der IDE von EmBlocks 2.3.0 auf EMBitz 1.11.
   - Android App: Beim Start (oder auf Knopfdruck) werden die aktuellen Einstellungen von der Uhr geladen.
   - Android App: Es können bis zu vier Profile angelegt werden, um die Einstellungen für bis zu vier Uhren zu steuern.
   - Android App: Gamepad für Spiele wie z.B. Tetris

STM32 Version 2.5.0:

   - Neu: Einspielen von Updates für ES8266 und STM32 über OTA ("over the air").
   - Bugfix: Eingabe einer negativen Temperatur-Korrektur wird in einen positiven Wert geändert.
   - Optimierungen der LED-Treiber zwecks Minimierung des RAM-Speicherverbrauchs.
   - Insgesamt 30 Varianten der STM32-Firmware verfügbar

STM32 Version 2.4.2:

   - Neu: Hochauflösendes animiertes Piktogramm "Fireworks" für WC24h.
   - Bugfix: Auftretendes Glimmen nach Anzeige eines Piktogramms eliminiert. 
   - Bugfix WC24h: Anzeige Ossi-Modus: ES IST EINE MINUTE(N) NACH NEUN.
   - Bugfix WC24h: Nach Anzeige des Datums wurde die Uhrzeit nicht vollständig aktualisiert.

STM32 Version 2.4.1:

   - Bugfix: Date-Intervall wurde fälschlicherweise als Fireworks-Interval gespeichert.

STM32 Version 2.4.0:

   - Variable Größen der Piktogramme.
   - Sanftes Ein- und Ausblenden (Fading) der Piktogramme.
   - Piktogramme können nun animiert werden.
   - Neues animiertes Piktogramm "Feuerwerk" für Silvester.
   - Neue Animation "Flicker".
   - Anzeige des aktuellen Datums als Laufschrift.
   - Optimiertes Auslesen des DS18xx, um Verzögerungen in der Sekundenanzeige (Ambilight Clock) zu vermeiden.
   - UART-Ringbuffer vergrößert zwecks Stabilisierung des ESP8266-Flashvorgangs.
   - Unterstützung von neuen Layouts für Schweizerdeutsch und Englisch (nur WC12h).

STM32 Version 2.3.5:

   - Erkennung des (nicht existenten) externen Pullups verbessert durch Delay vor Messung.
   - Piktogramme Heart und Xmas-Tree werden nun in einer höheren Auflösung (16x16) auf der WC24h angezeigt.

STM32 Version 2.3.4:

   - Bugfix: Piktogrammanzeige bei automatischer Helligkeitsregelung korrigiert.
   - Bugfix: Piktogramme werden bei Power-Off nicht mehr angezeigt.

STM32 Version 2.3.3:

   - Compiler-Warnungen für SK6812-RGBW beseitigt.

STM32 Version 2.3.2:

   - Bugfix: Anzeigefehler von Piktogrammen auf WC24h behoben.

STM32 Version 2.3.1:

   - Bugfix: Anzeige von Piktogrammen bei gleichzeitiger Rainbow-Animation zu kurz.

STM32 Version 2.3.0:

   - Bugfix: Ineinanderschieben von Buchstaben bei Ticker-Anzeige behoben.
   - Bugfix: Änderungen von Weiß-Werten bei SK6812-RGBW wurden nicht mehr übernommen.
   - Piktogramme "Heart" und "Xmas Tree" eingebaut.
   - Unterstützung für WS2812 mit Reihenfolge RGB statt GRB.
   - Spezielle Compiler-Warnungen bei erhöhter Warnstufe beseitigt.

STM32 Version 2.2.4:

   - Automatische Umschaltung auf Open-Drain-Betrieb des LED-Ausgangs bei Anbringung eines 4k7 Pullups am WS2812-Eingang zur Erhöhung des LED-Eingangspegels von 3,3V auf 5V.

STM32 Version 2.2.3:

  - Bugfix: Unbedingtes Aktivieren des AP-Modus durch User-Button, auch wenn der ESP wegen Hersteller-Einstellungen bereits im AP-Modus ist.

STM32 Version 2.2.2:

  - Bugfix: Regeln der weißen SK6812-RGBW-LED im Browser funktionierte nicht mehr.

STM32 Version 2.2.1:

 - Bugfix: Wenn ausschließlich das RTC-Modul zur Temperaturmessung dient, wurde auf dem Display immer fälschlicherweise 12°C ausgegeben.
 - Bugfix: Korrekturwert für DS18XX geht nach Reboot verloren.
 - SK6812 wird nun auch in der RGB-Variante unterstützt - nicht nur RGBW.
 - Verbesserung der automatischen Helligkeitsregelung (Sprungverhalten bei Unterschreiten der Helligkeits-Mindestwerts).
 - DCF77-Empfänger-Problem bei Sekunde = 50 (gleichzeitige DS18xx-Temperaturmessung) behoben.

STM32 Version 2.2.0:

 - Bugfix: Die Anzeigedauer der Temperatur ist nun nicht mehr von der Dauer der Animation abhängig.
 - Bugfix Ambilight: Nach "Test Display" wurde die ursprüngliche Helligkeit des Ambilight nicht wieder hergestellt.
 - Bugfix AP-Mode: Durch einen Timeout bei der ESP8266-Kommmunikation wurden die Vorgabewerte fürs Web-Interface nicht übertragen.
 - RX-Ringbuffer ESP8266 -> STM32 von 128 auf 256 vergrößert.
 - Timeout-Behandlung bei der Kommunikation zwischen STM32 und ESP8266 verbessert. 
 - Web-Interface: Checkbox "Use display colors" wurde auf die Seite "Ambilight" verschoben.
 - WC12h Bugfix: Umlaute werden in der Laufschrift immer als Großbuchstaben angezeigt.
 - WC12h: Font zur Laufschriftanzeige durch besser lesbaren Font ersetzt.
 - WC24h: Korrektur der Anzeige von "ES IST EINS UHR" nach "ES IST EIN UHR" in bestimmten Anzeigemodi.
 - Bugfix SK6812: Rot und Grün vertauscht.
 - Bugfix LDR: Nach dem Setzen eines neuen LDR-Max-Wertes wurde dieser nicht zurück an das Web-Interface
   übertragen und deshalb dort (bis zum nächsten Reboot) ein alter Max-Wert angezeigt.

STM32 Version 2.1.0:

 - Auslagerung des HTML-Codegenerators auf den ESP8266, damit Code-Ersparnis auf dem STM32 von 14KB Flash.

 - Laufschrift mit dem aktuellen Wetter (über openweathermap.org)

 - Unterstützung SK6812 (optional, RGBW-LEDs)

 - Verbesserungen bei der LDR-Umgebungshelligkeitsmessung

 - Wegfall der Schaltfläche "Save all" im Web-Interface. Nun werden sämtliche geänderten Konfigurationsdaten sofort
   auch im EPROM neu gespeichert.

 - Bugfix: DS18xx-Temperatur-Korrekturwert wurde bisher als RTC-Temperatur-Korrekturwert im EEPROM gespeichert.

 - Bugfix: Bei der manuellen Eingabe des aktuellen Datums/Uhrzeit im Webinterface wurde das Jahr bisher als
   "Zufallszahl" gespeichert, wenn der ESP8266 im AP-Modus läuft, weil kein WLAN vorhanden ist.

STM32 Version 2.0.7:

 - URL-Fehler im Web-Interface korrigiert für Rainbow-Geschwindigkeit und Temperatur-Anzeige-Intervall

 - Fehlende Berücksichtung der Animation-Geschwindigkeiten in "Random" eingebaut

 - Default-Werte für einstellbare Verzögerungen der Animationen auf WC12h verdoppelt

STM32 Version 2.0.6:

 - Neue Animation "Drop"

 - Neue Animation "Squeeze"

 - Geschwindigkeitsregler für sämtliche Animationen

 - Angaben von Favoriten für die Animationen, die dann bei der Random-Animation ausgewählt werden sollen

 - Geschwindigkeitsregler für Rainbow - sowohl für Display als auch für Ambilight

 - Angabe von Temperaturkorrekturen für DS18xx als auch für RTC in Schritten von 0,5°C bei Selbsterwärmung

 - LED-Kalibrierung durch Messen vom dunkelsten und hellsten Wert manuell im Web-Interface möglich - ungetestet!

 - Clock und Clock2 auf dem Ambilight laufen nun je nach Einstellung in der Display-Farbe oder selbstständig in der Ambilight-Farbe

 - Temperatur-Anzeige auf der WC12h nun nicht mehr als Laufschrift, sondern durch zwei große Ziffern auf dem Display.
   Wenn die Temperatur xx,5°C und nicht xx,0°C beträgt, wird das "standesgemäß" auf der WC12h durch zwei leuchtende
   Minuten-LEDs angezeigt. Die Anzeige der Minuten-LEDs ist ungetestet.

 - Angabe eines Intervalls, wie oft die Temperatur automatisch eingeblendet werden soll. Bei "1" wird die Temperatur einmal
   pro Minute eingeblendet, nämlich immer um hh:mm:30. Bei Angabe von z.B. "5" passiert das dann halt nur noch alle
   5 Minuten. Wird 0 oder nichts eingegeben, wird keine Temperatur automatisch eingeblendet.

STM32 Version 2.0.5:

 - Neue Animation: "Matrix".
 - Bugfix: Fehler in Timerfunktion am Wochenende behoben.
 - Bugfix: Fehlerhafte Offset-Berechnung in Ambilight-Animation "Clock2" korrigiert.

STM32 Version 2.0.4:

 - Bugfix: Ambilight leuchtete im Synchronmodus in Rainbow-Animation nach Abschalten durch Timer weiter. Die LEDs werden nun komplett abgeschaltet.
 - Bugfix: Getrennte Helligkeitssteuerung des Ambilights wurde durch Helligkeitssteuerung des Displays beeinträchtigt. Nun sind beide Helligkeiten komplett unabängig.
 - Bugfix: Wenn die Uhr gem. Timer aus ist, liefen einige Animationen teilweise trotzdem alle 5 Minuten. Ist nun behoben.
 - Bugfix: Keine Webserver-Kommunikation möglich, wenn der ESP-01 im AP-Modus ist und in der RTC die Uhrzeit noch nicht initialisiert wurde. Ist nun behoben.
 - Neu: Anzeige von Laufschriften
 - Ambilight: Sekundenzeiger nun auch für 20 oder 30 LEDs, die Zahl der Ambilight-LEDs ist nun im Webinterface konfigurierbar.
 - Ambilight: Neue Sekundenanzeige mit zunehmendem/abnehmendem Vollkreis.
 - Ambilight: Sekundenzeiger-Animationen: Start-LED nun über Webinterface konfigurierbar
 - Web-Konfiguration: Erweiterung der Schieberegler um numerische Anzeige (zwecks besserer Reproduzierfähikeit von RGB-Werten)

STM32 Version 2.0.3:

    Bugfix: einminütiges Abschalten des Displays nach Cube-Animation behoben.

STM32 Version 2.0.2:

    Um unnötige Animationen zur vollen Minute bei der WC12h zu vermeiden, wird die DCF77-Zeit nun um hh:mm:15
    verzögert ausgeliefert. Timeserver-Zugriffe pendeln sich im Laufe der Zeit auf hh:mm:30 (alle 3780 Sekunden)
    ein, RTC-Zugriffe werden jede Minute um hh:mm:45 ausgeführt.
    Power-Taste auf der IR-Fernbedienung kann nun beim Anlernen als Skip-Taste verwendet werden.
    DCF77-Messung: Die Zeit der vorherigen Minute wird nun als zusätzliche Plausibilitätsprüfung herangezogen
    Snake-Animation: Es werden nun gezielt die Wörten der alten Uhrzeit "gefressen".
    
STM32 Version 2.0.1:

    Konfiguration von "ES IST"-Anzeige korrigiert: nun auch jede halbe Stunde.
    Bugfix bei der "ES IST"-Anzeige auf WC12h: Die Anzeige wird nun 5 Minuten lang beibehalten - und nicht nur ein Minute.
    Bugfix: Farbanimationen bzw. Ambilight-Animationen verhinderten das Abschalten des Ambilights bei Power-Off.
    Umgebungs-Helligkeitsmessungen werden nun nur noch durchgeführt, wenn keine Übergangs-Animation läuft.
    Anzahl der möglichen Ambilight-LEDs nun bei Verwendung eines Nucleo-Board gleich 100, sonst 60.
    Power-Off-Signal, um LED-Spannungsversorgung abzuschalten, nun beim Mini-Board (STM32F103) auf Pin PB0.
    Fading-Effekt durch kleinere Farbänderungsschritte verstärkt.

STM32 Version 2.0.0:

    Bugfix: Abschalten des Ambilights bei Power-Off-Befehl
    Bugfix: Ein-/Ausschalten der Spannungsversorgung für LED-Stripe
    Anzeige von ".... UHR" zur vollen Stunde - dort, wo es bisher fehlte
    Neue Einstellung, ob "ES IST" permanent leuchten soll oder nur zur vollen Stunde
    Verbesserung der Rainbow-Animation (Dank an Ralf Hammeran)
    Dynamische Anpassung der automatischen Helligkeitssteuerung an die Umgebungshelligkeit (Dank an Ralf Hammeran)
    Neue Übergangs-Animationen: "Snake", "Teletype" und "Cube"
    Anzahl der möglichen Ambilight-LEDs auf 60 Stück begrenzt (vorher 100)
    Neue Seite "Ambilight" in der Web-Konfiguration
    Neue Einstellung, ob Ambilight-Farben synchron zu den Display-Farben angepasst werden sollen
    Neue separate Farbauswahl und Helligkeitssteuerung für Ambilight
    Neuer Ambilight-Modus "Clock": Umlaufende Sekundenanzeige
    Neuer Ambilight-Modus "Rainbow": Regenbogenfarben-Animation jetzt auch im Ambilight möglich

STM32 Version 1.9.0:

    Neu: Automatischer Farbwechselmodus: Rainbow

STM32 Version 1.8.9:

    Stellen der Uhrzeit über Web-Interface
    Konfiguration über Web-Interface, ob ESP8266 im AP- oder WLan-Client-Modus arbeiten soll
    Einstellung SSID und Key für AP-Modus
    Steuerung der LED-Stripe-Spannungsversorgung (ungetestet)

STM32 Version 1.8.8:

    Für WC12h kleineren Font (5x8) für Laufschriften zwecks besserer Lesbarkeit integriert
    Auswertung des Temperatur-Anzeige-Kommandos per Android App (ab Version 1.7.0)

STM32 Version 1.8.7:

    Fehler in der Wochentagsberechnung korrigiert

STM32 Version 1.8.6:

    Verzögerte Reaktion der Minuten-LEDs (WC12h) bei Farbwechsel behoben

STM32 Version 1.8.5:

    STM32F103 Mini Development Board: Abschalten des JTAGS, um PB3 u.a. als GPIO für z.B. IRMP nutzen zu können (nicht relevant für Nucleo-Variante)

STM32 Version 1.8.4:

    Korrektur der ESP8266 Flash-Pin-Definition für das STM32F103 Mini Development Board (nicht relevant für Nucleo-Variante)

STM32 Version 1.8.3:

    Bugfix bei der Temperatur-Anzeige: Es wurde immer die DS3231-Temperatur statt der DS128xx-Temperatur gezeigt
    Falsche Temperatur-Anzeige im Modus "Temperatur"
    Bezeichnungen der Anzeigemodi für WC24 gekürzt
    Manuelle Aktivierung des LDRs aus Weboberfläche entfernt. LDR-Messung ist nun immer aktiv, egal ob angeschlossen oder nicht
    Unterstützung des DCF77-Moduls wieder eingebaut
    Anzahl der Nachtschaltzeiten auf 8 erhöht - unter Berücksichtigung der Wochentage

STM32 Version 1.8.2:

    Hangup-Problem bei Aktivieren des LDRs beseitigt
    Neu: Nachtschaltzeiten in der Weboberfläche
    Optimierung des HTML-Code-Generators

STM32 Version 1.8.1:

    Fehler bei HTTP-Get-Parameter-Übergabe von Leerzeichen in SSID behoben

STM32 Version 1.8.0:

    Spezielle Firmware für ESP8266-Modul, da die Espressif-Firmware zu instabil ist und zuviele Varianten existieren
    Kommunikationsprotokoll an neue ESP-Firmware angepasst
    Direktes Flashen des ESP8266 in der WordClock-Schaltung über das verwendete STM32-Board
    Diverse kleinere Bugfixes

Änderung: Damit das ESP8266-Modul direkt über das STM32-Board geflasht werden kann, ist die Verbindung ESP8266-GPIO0 zu STM32 PA4 herzustellen, siehe auch: Anschluss ESP8266

STM32 Version 1.7.0:

    MCURSES-Monitor durch WEB-Server ersetzt
    Laufschriften-Ausgabe der aktuellen IP-Adresse
    Kleinere Änderungen/Optimierungen
    DCF77-Decoder mangels Interesse/Notwendigkeit entfernt
    Laufschriften-Ausgabe auf dem LED-Display beim Anlernen einer IR-Fernbedienung

STM32 Version 1.6.3:

    WordClock12h: Anzeige der Temperatur durch Laufschrift
    Neue Anschlusspins für TSOP und DS18xxx am STM32F103
    Optimierung des WS2812-DMA-Transfers für STM32F103
    Temperaturmessung mit DS3231, wenn kein DS18xx angeschlossen
    Umstrukturierung der C-Sources

STM32 Version 1.6.2:

    Problem beim Verbindungsaufbau Andoid App -> WordClock behoben

STM32 Version 1.6.1:

    Zusätzliche Unterstützung der "klassischen" WordClock12h mit 10x11 LEDs
    Anpassung der MCURSES-Monitor-Oberfläche an WordClock12h-Variante
    Portierung auf STM32F103 abgeschlossen (IDE-Projekt folgt mit 1.6.2)
    Zusätzliche Unterstützung von neueren ESP8266-Firmware-Versionen 1.0.1, 1.4.0 und 1.5.0.
    Optionales ESP8266-Debugging auf zusätzlichem USART - nur für Entwickler

STM32 Version 1.6.0:

    Neben dem TIME-Protokoll (TCP) wird nun auch NTP (UDP) unterstützt - für ESP-Firmware-Versionen ab 0018000902.

STM32 Version 1.5.9:

    Unterstützung der neueren ESP Versionen 0020000903 und AT 0.21.0.0
    Vergrößerung der UART-FIFOs
    Verallgemeinerung der UART-Funktionen zwecks besserer Konfiguration
    Überarbeitung der MCURSES-Monitor-Oberfläche

STM32 Version 1.5.8:

    Bugfix: Fehler in 1.5.7 (Falsche Behandlung des DMA-Buffers) wurde behoben
    Neu: Bis zu 100 weitere LEDs hinter der Buchstabenkette werden als Ambilight angesteuert

STM32 Version 1.5.7:

    Bug in uart-Code für STM32F103 beseitigt - irrelevant für Nucleo STM324xx
    Timing für WS2812B angepasst, es werden nun WS2812 und WS2812B unterstützt
    Anzahl der möglichen WS2812-LEDs ist nun variabel gehalten. Das ist Voraussetzung für das demnächst verfügbare Ambilight.

STM32 Version 1.5.6:

    Unterstützung von ESP8266 mit neuerer Firmware, welche \r\n statt \r erwartet
    Unterstützung von verschiedenen Baudraten des ESP8266-Moduls
    Automatische Umschaltung von 9600Bd auf 115200Bd beim ESP8266

STM32 Version 1.5.5:

    Optimierungen im LED-Display-Code
    Diverse Anpassungen an STM32F103

STM32 Version 1.5.4:

    Automatische IR-Anlernroutine in den ersten 3 Sekunden ab Programmstart
    Kleiner Bugfix bei den möglichen Helligkeitsstufen (Dimmer)

STM32 Version 1.5.2:

    Anzeige der Firmware-Version des ESP8266-Moduls im MCURSES-Monitor
    Korrektur in den Worttabellen für die Wörter ACHT und VIER in der zehnten Reihe

STM32 Version 1.5.1:

    Manuelle Helligkeitsregelung per MCURSES-Monitor / IR-Fernbedienung / Android App eingebaut
    Automatische Helligkeitsregelung per LDR nun über MCURSES-Monitor / IR-Fernbedienung / Android App ein-/ausschaltbar

STM32 Version 1.4.2:

    Die geladenen aus dem EEPROM RGB-Werte wurden nach dem Boot nicht mehr sofort übernommen. Ist korrigiert.

STM32 Version 1.4.1:

    Initialisierung des ADC korrigiert
    Automatische Helligkeitsregelung dunkelt nicht mehr so stark ab.

STM32 Version 1.4.0:

    Automatische Helligkeitsregelung mittels LDR
    Helligkeitsstufen von 32 auf 64 erhöht
    LED-Testprogramm eingebaut (Taste 'T' im MCURSES-Monitor)
    Anzeige des DS18xxx-Typs im MCURSES-Monitor)
    Unterstützung für Status-LED (beachte geändertes LED-Anschluss-Schema!)
    Android App an 64 Helligkeitsstufen angepasst

STM32 Version 1.3.1:

    Sporaisches Hangup-Problem nach Auslesen der Temperatur behoben
    Fehler bei der Erkennung des Family-Codes für DS18xxx beseitigt
    Optimierung des Zeitverhaltens beim Zugriff auf OneWire-Bus
    Optimierung des WS2812-Codes

STM32 Version 1.3.0:

    Unterstützung von DS18xxx-Temperatursensoren
    Temperatur-Anzeige innerhalb +10°C und 39,5°C
    Korrektur Sommerzeitumstellung
    Keine Unterstützung mehr von STM32F4-Discovery

STM32 Version 1.2.0:

    IRMP-Konfigurationsfehler behoben

STM32 Version 1.1.0:

    Animationen hinzugefügt
    Neue Tabellen für Uhrzeit und Temperatur

STM32 Version 1.0.0:

    Test auf verschiedene Adressen des I2C-EEPROMs
    EEPROM-Speicherplatzverbrauch minimiert
    RTC DS3231-Routinen auf DS1307 verallgemeinert
    Network Listener (UDP) zum Fernsteuern der Uhr über WLAN
    Android App zum Fernsteuern der Uhr (Ein/Aus, Farben, Anzeigemodus)

STM32 Version 0.9.1:

    EEPROM-Hexdump im MCURSES-Monitor eingebaut
    Zusätzliche Waitstates beim Beschreiben des EEPROMs

STM32 Version 0.9:

    Zusätzlicher Anschluss von RST und CH_PD des ESP8266-Moduls
    Verbesserung der ESP8266-Konfiguration dank Hardware-Reset
    Nutzung des Stromsparmodus im ESP8266, wenn die Anzeige abgeschaltet wird
    Konfiguration der Zeitzone über MCURSES-Monitor
    Test und Überarbeitung der EEPROM und RTC-Funktionen
    Synchronisation der RTC-Zeit mit dem µC-Timer
    Speichern folgender Daten im EEPROM:

    EEPROM-Version
    IRMP-Daten einer angelernten IR-Fernbedienung
    Aktuell eingestellte Farben und Anzeigemodus
    IP-Adresse des Timeservers
    Zeitzone

STM32 Version 0.8:

    Neue IR-Fernbedienungs-Tasten POWER und OK
    Einbau einer konfigurierbaren "Nachtzeit", in der sich die Uhr selbstständig abschaltet
    Konfiguration des Timeservers über MCURSES-Monitor
    Speichern/Laden sämtlicher Konfigurations-Daten in externem EEPROM
    Initialisierung des ESP8266 verbessert (warten, bis nach PowerOn eine WLAN-Verbindung besteht)
    Aufteilung der Anzeige-Logik und des MCURSES-Monitors auf dsp.c und monitor.c
    Aufteilung der ESP8266-Routinen auf esp8266.c (low-level) und timeserver.c (high-level)
    Diverse Optimierungen - u.a. durch Einsatz von uint_fast8_t
    Diverse Bugfixes

STM32 Version 0.7.1:

    Portierung der Software auf STM32F411RE Nucleo-Board

STM32 Version 0.7:

    Portierung der Software auf STM32F401RE Nucleo-Board
    uart2.c generalisiert auf uart.c (verschiedene UARTs möglich)
    Bugfix im UART-Ringbuffer-Code (Interrupt-Sperre)
    Anzeige der Online-Devices (ESP8266, DCF77, EEPROM, RTC) im Terminal
    Verschiedene Optimierungen

STM32 Version 0.6:

    Konfiguration des WLAN-Moduls (SSID & Key) nun über Terminal statt fest im Code verdrahtet.
    Einstellung der Zeitzone möglich. Standard ist GMT+1, also mitteleuropäische Zeit.
    DCF77- und ESP8266-Modul-Aktivierung automatisch - keine Einstellung mehr im Code notwendig.
    I2C-Lib hinzugefügt (noch ungetestet und daher noch nicht verwendet).
    I2C-EEPROM-Modul hinzugefügt (noch ungetestet und daher noch nicht verwendet).
    I2C-RTC-Modul (DS3231) hinzugefügt (noch ungetestet und daher noch nicht verwendet).

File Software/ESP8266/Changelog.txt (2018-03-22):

ESP Version 2.8.3:

   - Overlays: Display-Button wieder eingebaut.

ESP Version 2.8.2:

   - Änderungen der Brightness Tabellen wirken sich nun unmittelbar auf die Anzeige aus.

ESP Version 2.8.1:

   - Bugfix: Fehler bei Local Update behoben.

ESP Version 2.8.0:

   - Neue Konfigurationsseiten im Webinterface: Overlays und SPIFFS.
   - Neu: Geänderte Menüanordnung der Weboberfläche.
   - Auslagerung der Overlay-Icons ins SPIFFS des ESP8266.
   - Einige kleinere Bugfixes.

ESP Version 2.7.3:

   - Neu: Web-Interface: Abspielen eines Tracks per Button "Play".
   - Neu: Neue API-Funktion über UDP: Abspielen eines Tracks.
   - Neu: Einblenden eines Overlays per Button "Display".
   - Neu: Neue API-Funktion über UDP: Einblenden eines Overlays.

ESP Version 2.7.2:

    Bugfix: Wetterdaten wurden nicht mehr ausgegeben.

ESP Version 2.7.1:

   Bugfix: Formatieren des Flashs resultierte in Endlosschleife der Weboberfläche

ESP Version 2.7.0:

   Neue Web-Seite: "DFPlayer" zum Abspielen von MP3-Tracks bei vordefinierten Ereignissen.
   Webinterface: Neu: Power-Status Anzeige
   Webinterface: Neu: DFPlayer-Status-Anzeige
   Webinterface: Neu: Formatieren des ESP8266-SPIFFS Dateisystems
   Mehrere Bugfixes und mehr Fehlerbehandlungen im Source-Code.

ESP Version 2.6.6:

   OTA-Flash des STM32: Der Flash-Inhalt wird nun erst unmittelbar vor dem eigentlichen Flash-Vorgang gelöscht, d.h. nach allen Konsistenzprüfungen.

ESP Version 2.6.4:

   Bugfix in Local Update über OTA: Es wurde in 2.6.3 immer diejenige Datei geflasht, die zuletzt über das Remote Update heruntergeladen wurde.

ESP Version 2.6.3:

   Diverse Korrekturen in den STM32-OTA-Flash-Routinen.

ESP Version 2.6.2:

   Anpassung des Bootloaders an Nucleo STM32F4xx
   Ambilight-Mode Clock: 5 Sekunden Marker nun an- und abschaltbar

ESP Version 2.6.1:

   Bugfix: Das aktuelle Datum/Uhrzeit wurde im Webinterface nicht angezeigt.

ESP Version 2.6.0:

   Neu: WPS Button im Webinterface
   Neu: Liste der verfügbaren Access-Points im Webinterface.
   Neu: Abschaltbares Ambilight per WebInterface - ungetestet.
   Neu: Ein-/Ausschalten des Ambilights über Timer - ungetestet.
   Neu: Konfigurierbare Helligkeitskurve bei automatischer oder manueller Regelung.
   Neu: Geschwindigkeitsregelung der Ticker-Texte
   Neu: OTA-Update des STM32 nun auch mit Upload vom lokalen PC aus möglich.
   Neu: Konfigurierbarer Host und Pfad für OTA-Updates - geplant für die zukünftige Herausgabe von Pre-Testversionen im neuen Pfad "test".

ESP Version 2.5.1:

   Bugfix: Temperaturkorrekturwert für DS18xxx wurde in V2.5.0 nicht übernommen.
   Neu: Verbindung von ESP8266 zu BOOT0 des STM32 ist nun GPIO4 statt GPIO16.
   Neu: Verbinden des ESP8266 per WPS-Button oder über Web-Interface (im AP-Modus).
   OTA-Update des STM32 nun auch mit Upload vom lokalen PC aus möglich.

ESP Version 2.5.0:

    Neu: Unterstützung des ESP8266 ESP-12F
    Neu: Einspielen von Updates für ES8266 und STM32 über OTA ("over the air").
    Bugfix: Eingabe einer negativen Temperatur-Korrektur wird in einen positiven Wert geändert.

ESP Version 2.4.0:

    Neue Animation "Flicker"
    Neues Piktogramm "Fireworks"

ESP Version 2.3.0:

    Auswahl der Piktogramme "Heart" und "Xmas Tree".

ESP Version 2.2.0:

    Diverse Verbesserungen bei der Kommunikation zwischen STM32 und ESP8266

ESP Version 2.1.0b:

    Bugfix - Umlaute in Wettertexten wurden nicht korrekt gezeigt. Konvertierung der Umlaute von openweathermap-Inhalten von UTF8 nach ISO8859 nachgeholt.

ESP Version 2.1.0a:

    Bugfix - beim Wechseln in den AP-Modus wurde fälschlicherweise "0.0.0.0" als IP-Adresse statt 192.168.4.1 ausgegeben.

ESP Version 2.1.0:

    Auslagerung des HTML-Codegenerators auf den ESP8266
    Auslagerung der Schnittstelle zu Android-Geräten (Kommando-Interpreter) auf den ESP8266

ESP Version 1.2.0:

    Neu: Ausgabe des WLAN-Modus: WLAN-Client oder AP

ESP Version 1.1.0:

    Fehler im NTP-Client behoben: Bei vorherigen Timeouts kann eine alte Uhrzeit ausgegeben werden

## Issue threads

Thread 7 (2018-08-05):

Falsche Buchstaben werden beleuchtet

Nikos410, 2018-08-05:
Bei der Wortuhr werden manchmal falsche Buchstaben, zusätzlich zu den für die Zeitanzeige benötigten, beleuchtet. Der Fehler tritt spontan, ohne dass die Uhr bewegt wird, in unregelmäßigen Zeitabständen auf. https://i.imgur.com/IaSUqcK.jpg

piapia1991, 2018-08-06:
kannst du die Uhr Donnerstags ab 14Uhr  nochmal mitbringen? Dann koennen wir uns das genauer anschauen :)

Nikos410, 2018-08-06:
Okay, ich komme nach der Arbeit am Donnerstag mal vorbei

Closed 2018-11-29.

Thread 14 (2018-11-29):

stm initialisierung optimieren

d-ahrens, 2018-11-29:
-gpio init
-led init
-1. strang einschalten
-leds aus
-...
-6. strang einschalten
-leds aus
-1.zeile leds einschalten als status
-restliche peripherie inti und leds als status nutzen

---
-button für bootloader modus entprellen
-wenn esp nicht antwortet status leds und esp resetten/neu initialisieren
-watchdog für esp

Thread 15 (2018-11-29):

button/wlan funktionen optimieren

d-ahrens, 2018-11-29:
-wenn durch wps button ip 0.0.0.0 gesetzt wird muss beim drücken des AP taster die standard ip gesetzt werden
-mit dem ap taster soll das letzte funktionierende wlan wiederhergestellt werden können
-dazu evtl. letzte funktionierende wlan einstellungen gesondert speichern

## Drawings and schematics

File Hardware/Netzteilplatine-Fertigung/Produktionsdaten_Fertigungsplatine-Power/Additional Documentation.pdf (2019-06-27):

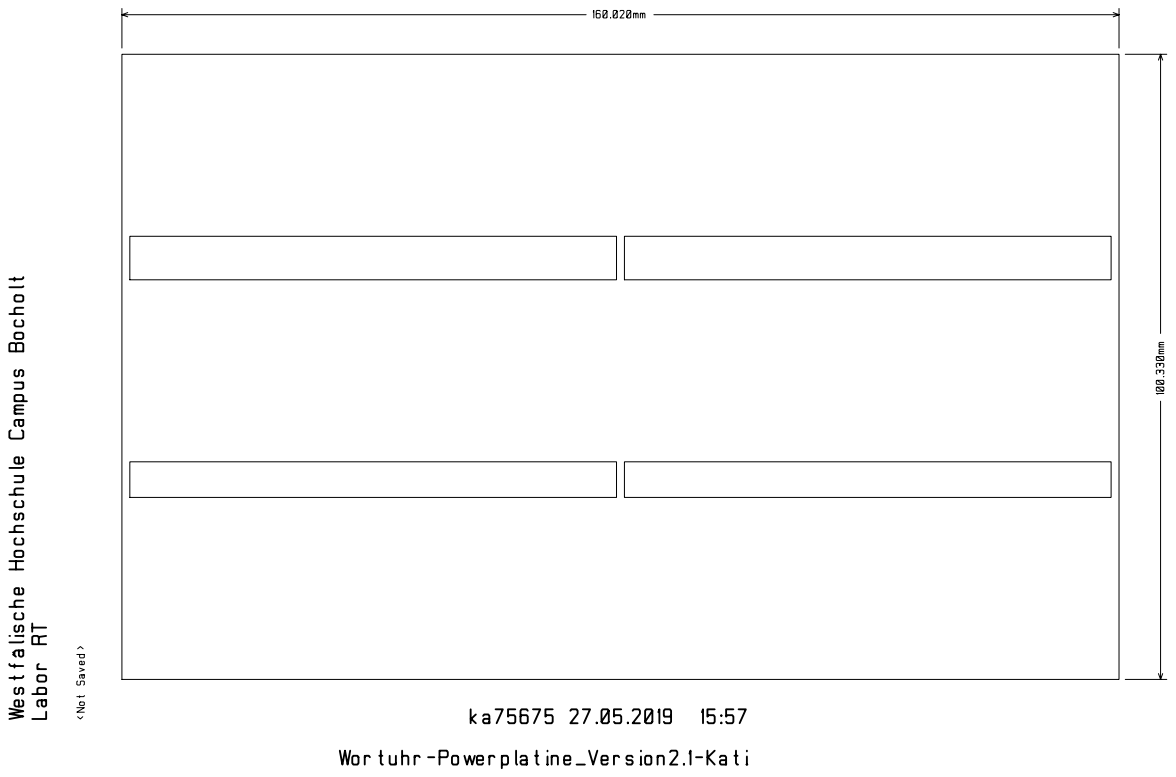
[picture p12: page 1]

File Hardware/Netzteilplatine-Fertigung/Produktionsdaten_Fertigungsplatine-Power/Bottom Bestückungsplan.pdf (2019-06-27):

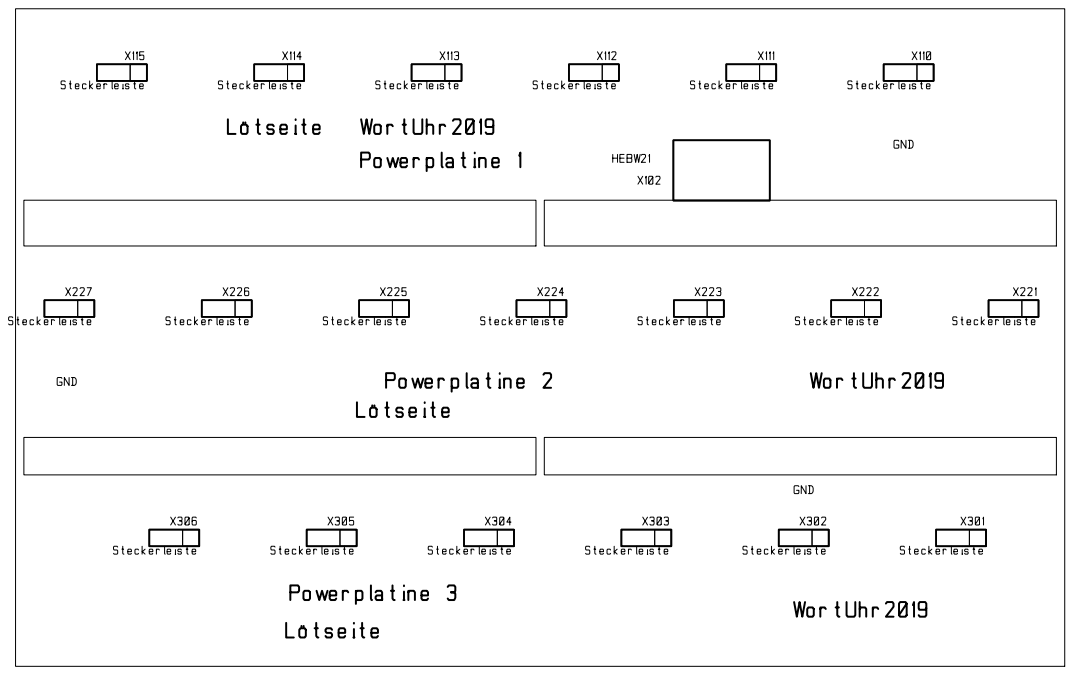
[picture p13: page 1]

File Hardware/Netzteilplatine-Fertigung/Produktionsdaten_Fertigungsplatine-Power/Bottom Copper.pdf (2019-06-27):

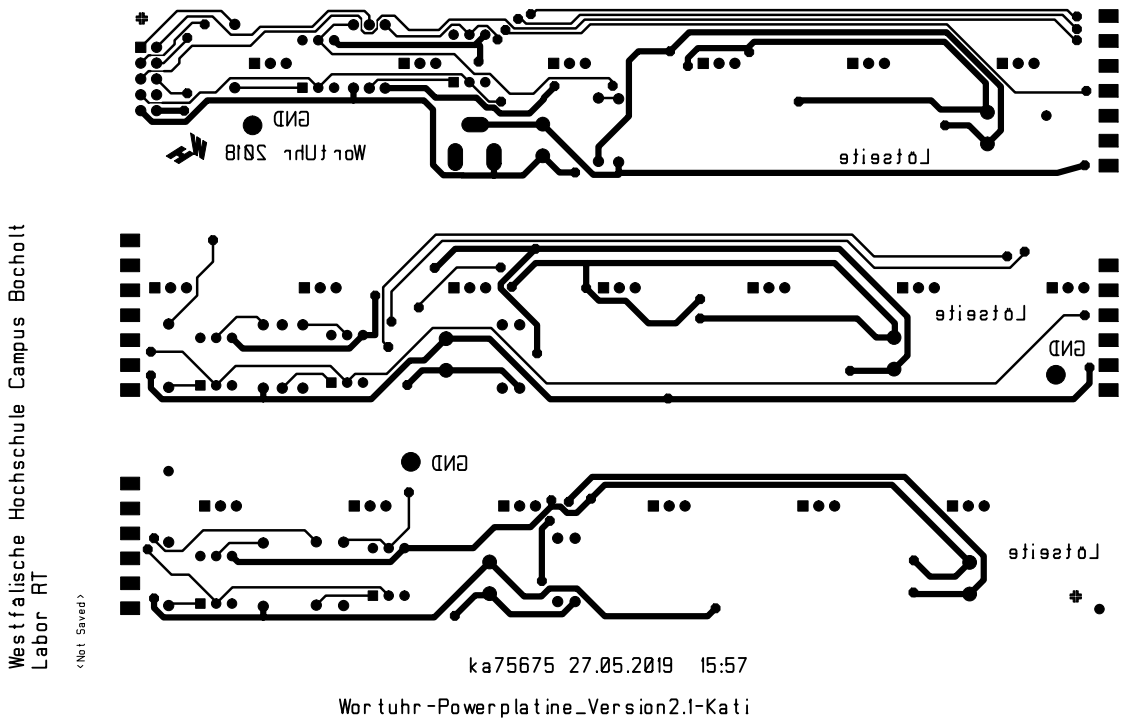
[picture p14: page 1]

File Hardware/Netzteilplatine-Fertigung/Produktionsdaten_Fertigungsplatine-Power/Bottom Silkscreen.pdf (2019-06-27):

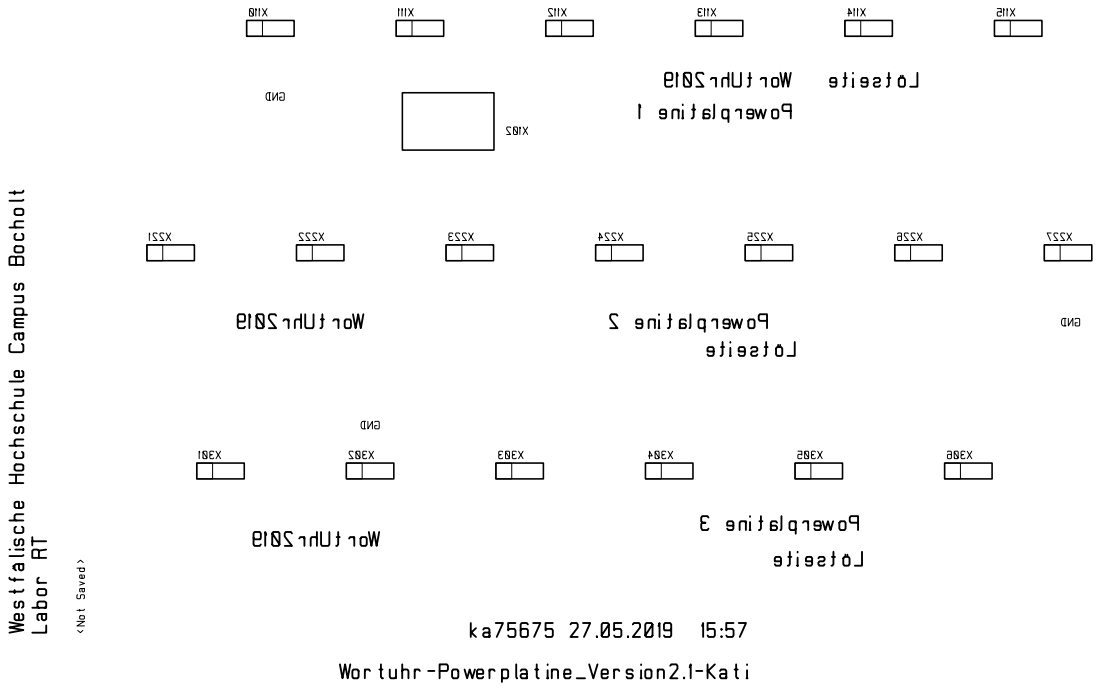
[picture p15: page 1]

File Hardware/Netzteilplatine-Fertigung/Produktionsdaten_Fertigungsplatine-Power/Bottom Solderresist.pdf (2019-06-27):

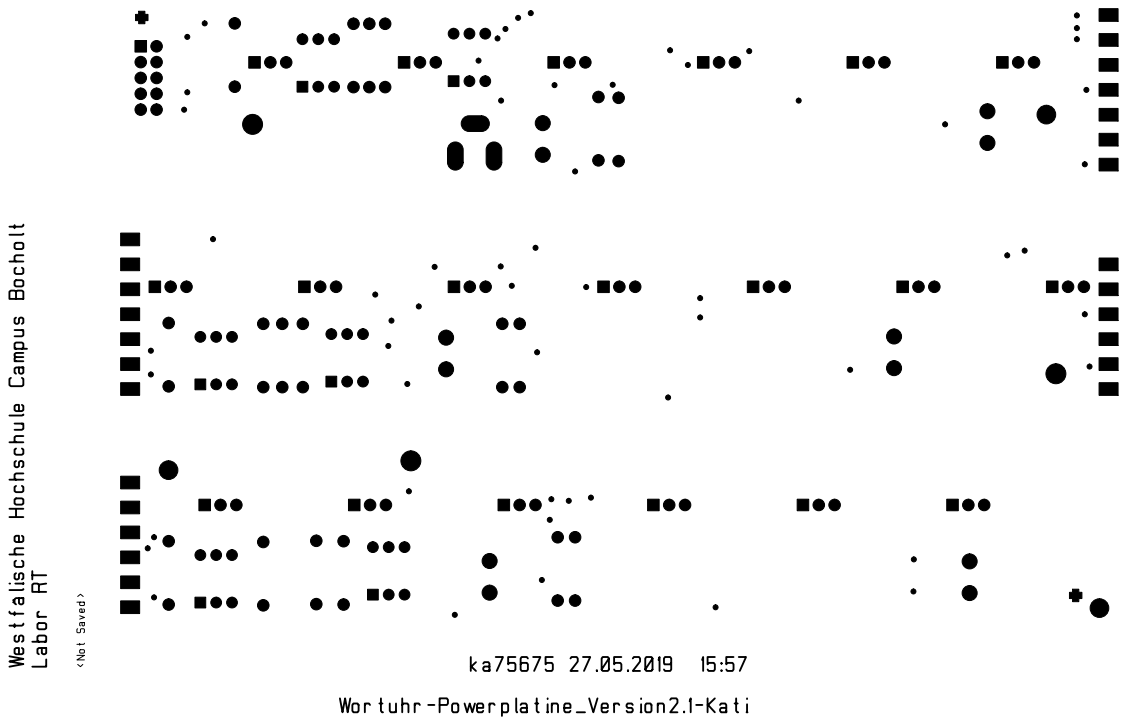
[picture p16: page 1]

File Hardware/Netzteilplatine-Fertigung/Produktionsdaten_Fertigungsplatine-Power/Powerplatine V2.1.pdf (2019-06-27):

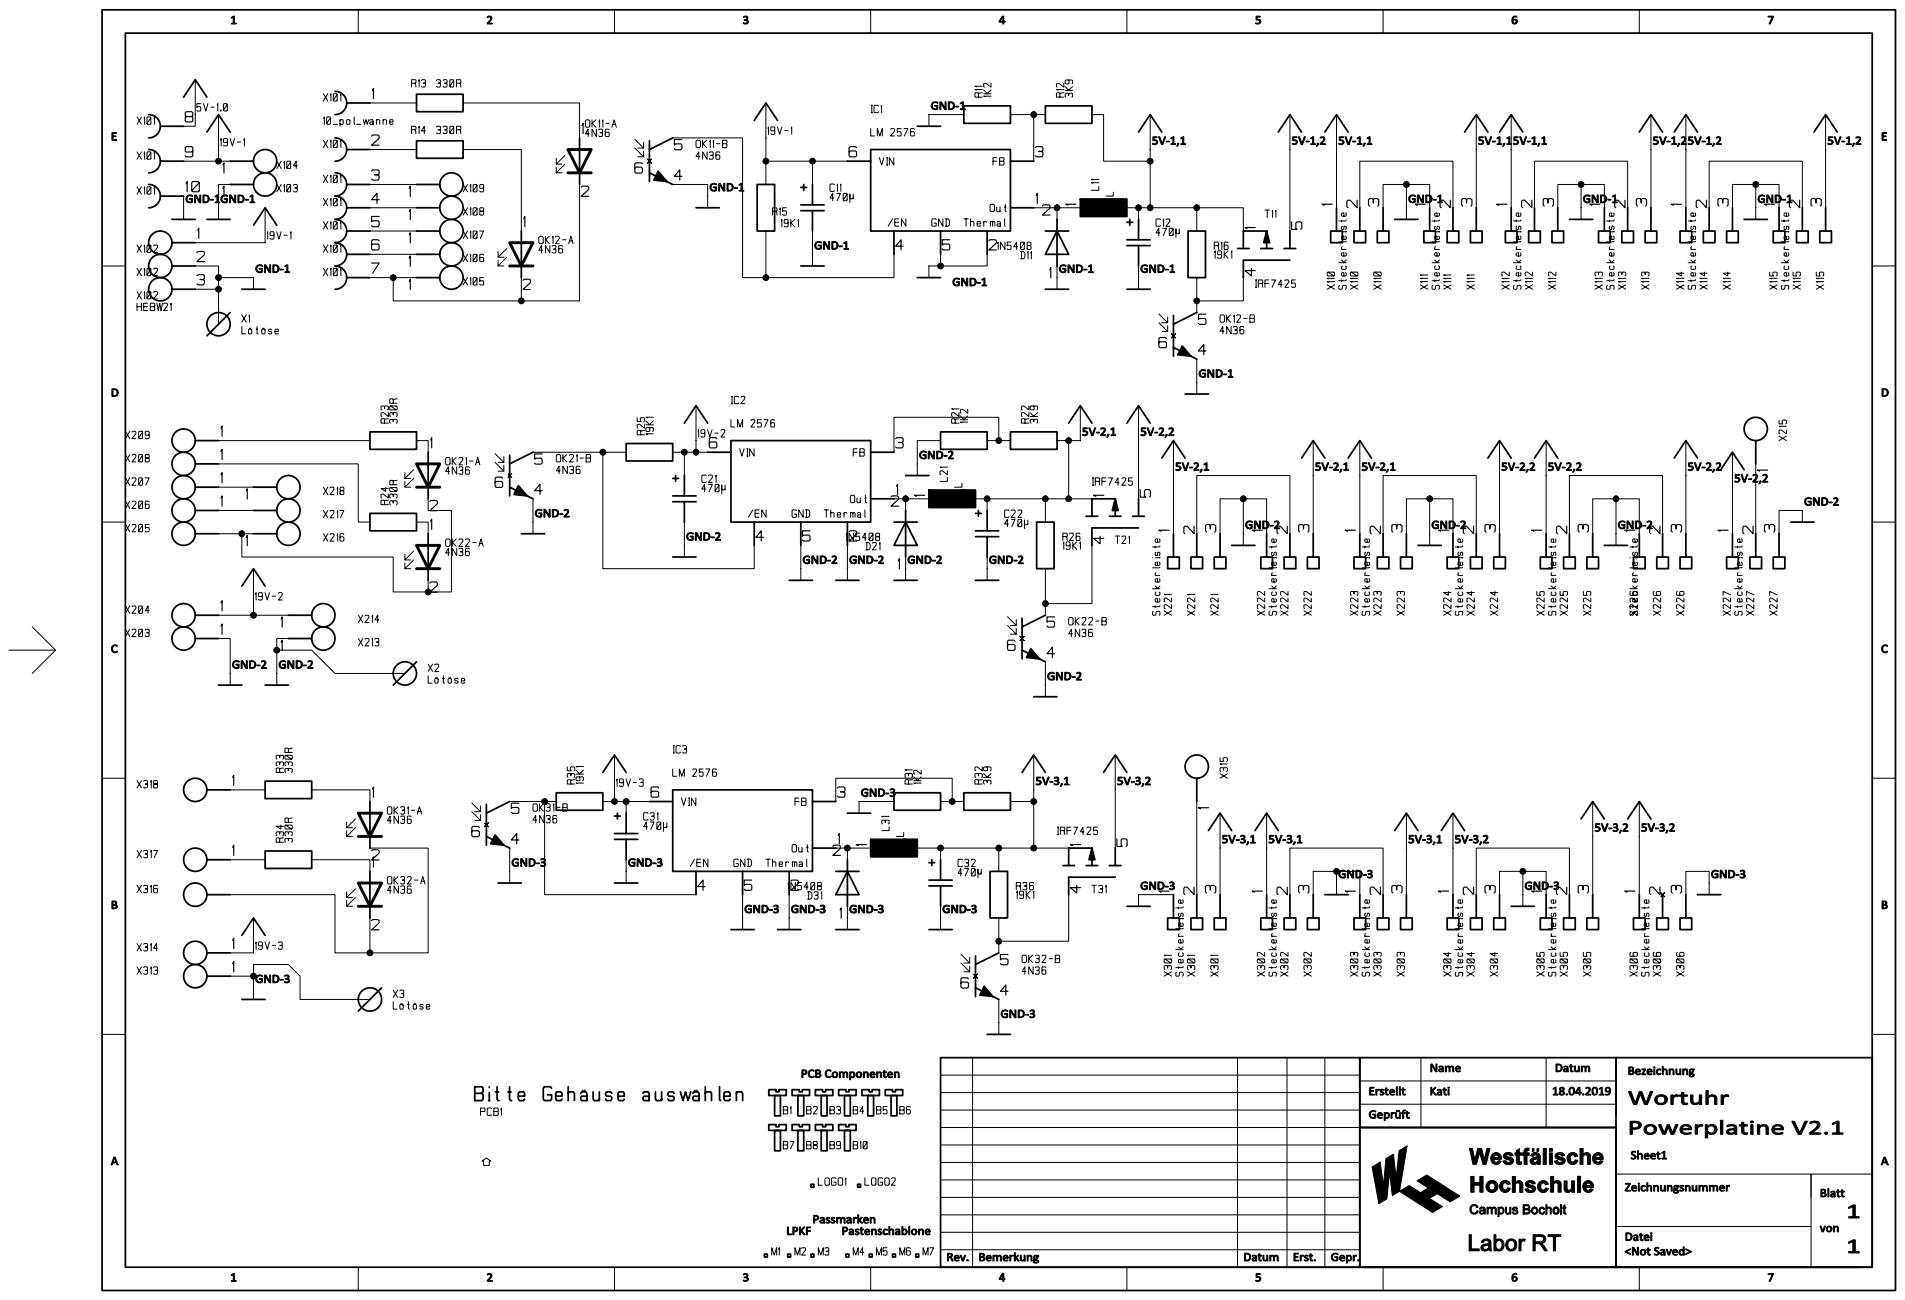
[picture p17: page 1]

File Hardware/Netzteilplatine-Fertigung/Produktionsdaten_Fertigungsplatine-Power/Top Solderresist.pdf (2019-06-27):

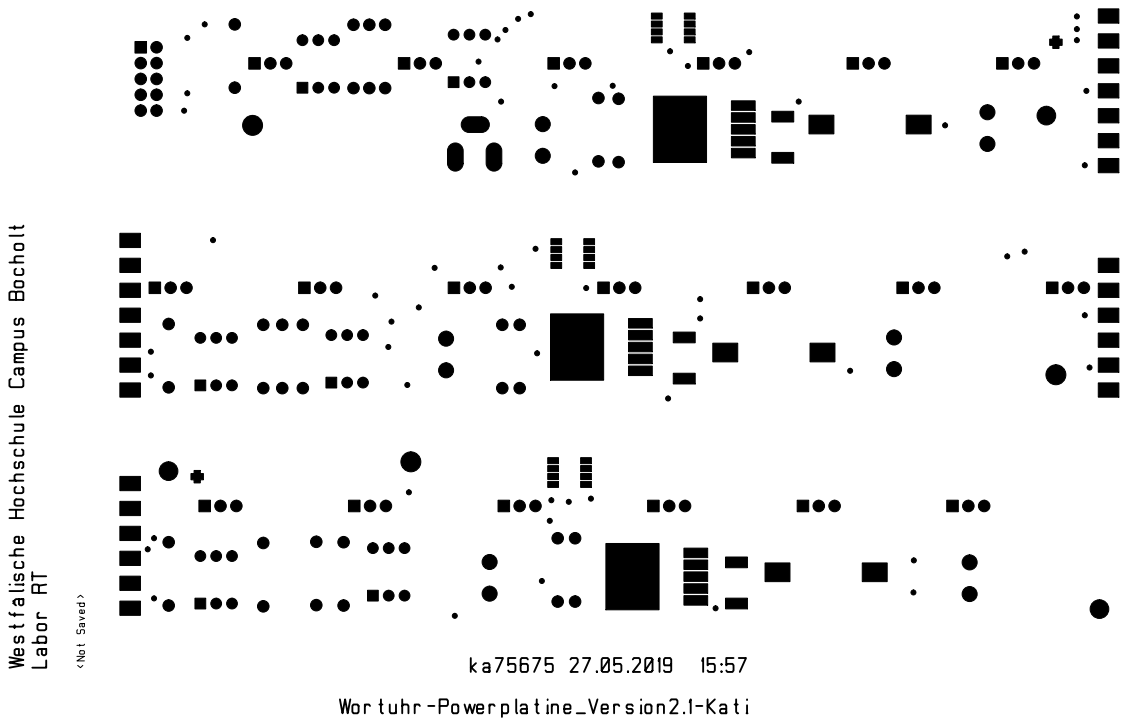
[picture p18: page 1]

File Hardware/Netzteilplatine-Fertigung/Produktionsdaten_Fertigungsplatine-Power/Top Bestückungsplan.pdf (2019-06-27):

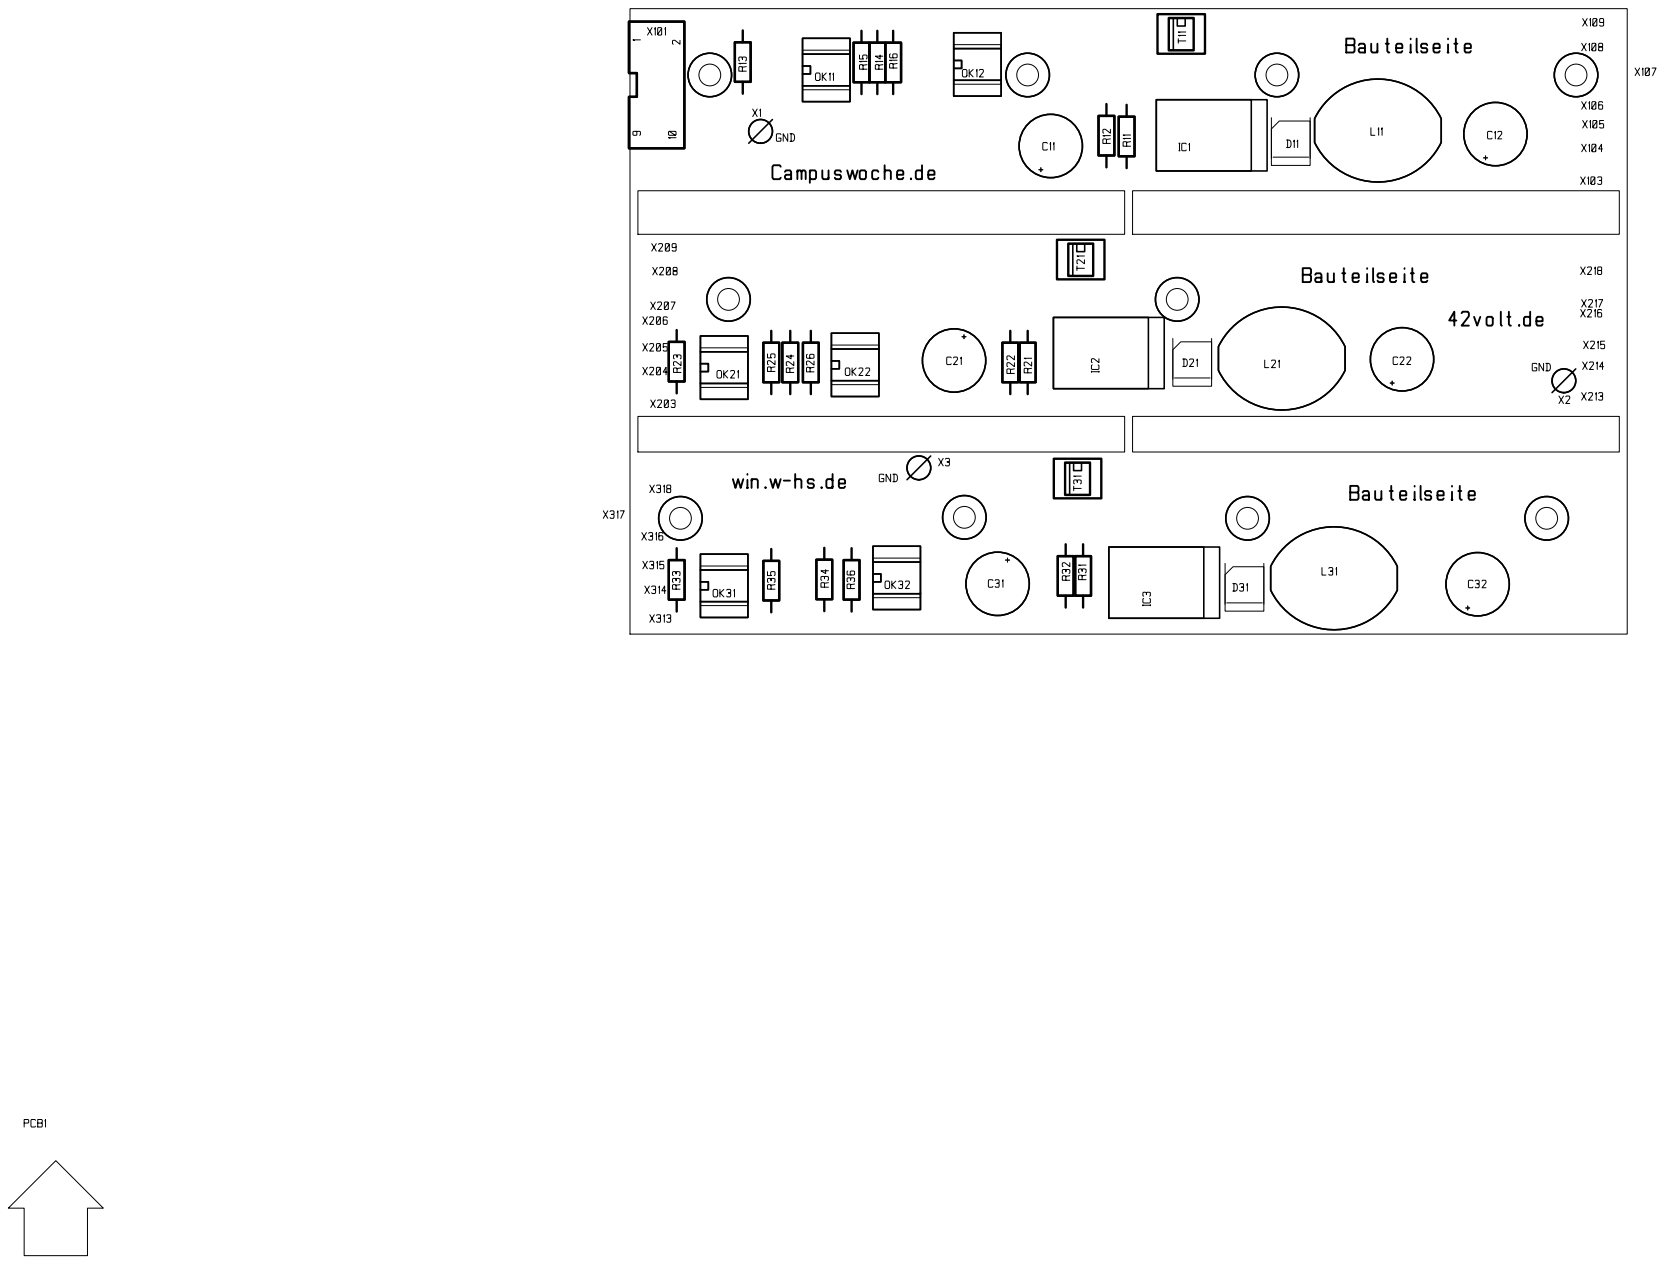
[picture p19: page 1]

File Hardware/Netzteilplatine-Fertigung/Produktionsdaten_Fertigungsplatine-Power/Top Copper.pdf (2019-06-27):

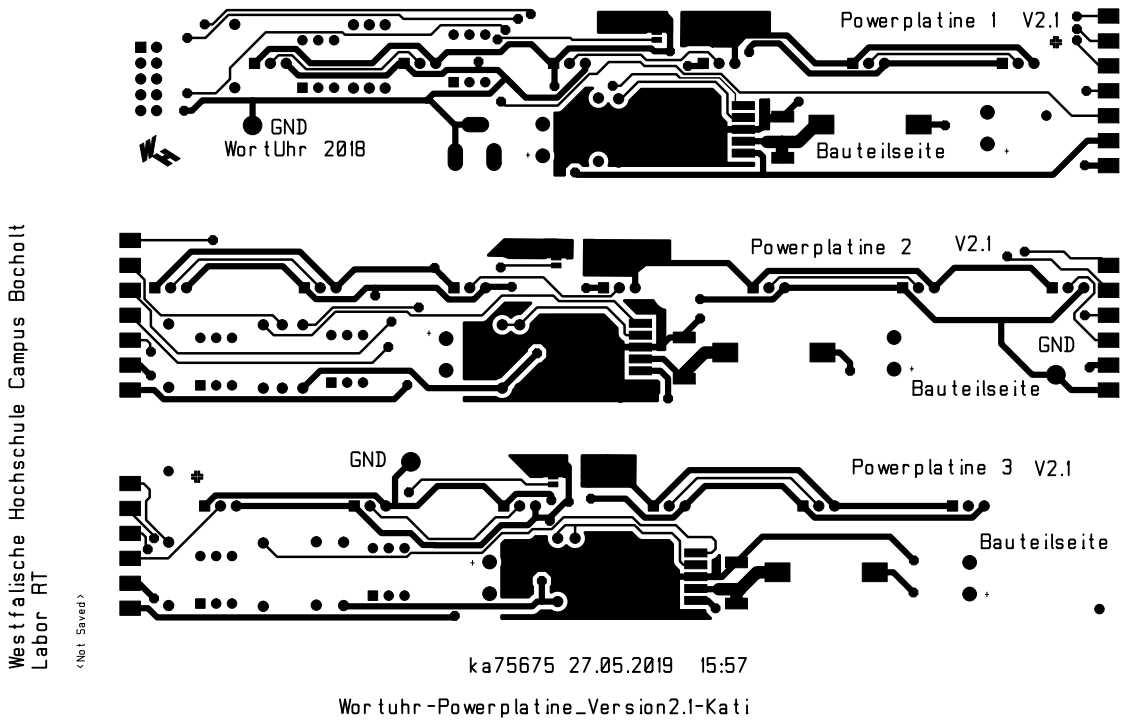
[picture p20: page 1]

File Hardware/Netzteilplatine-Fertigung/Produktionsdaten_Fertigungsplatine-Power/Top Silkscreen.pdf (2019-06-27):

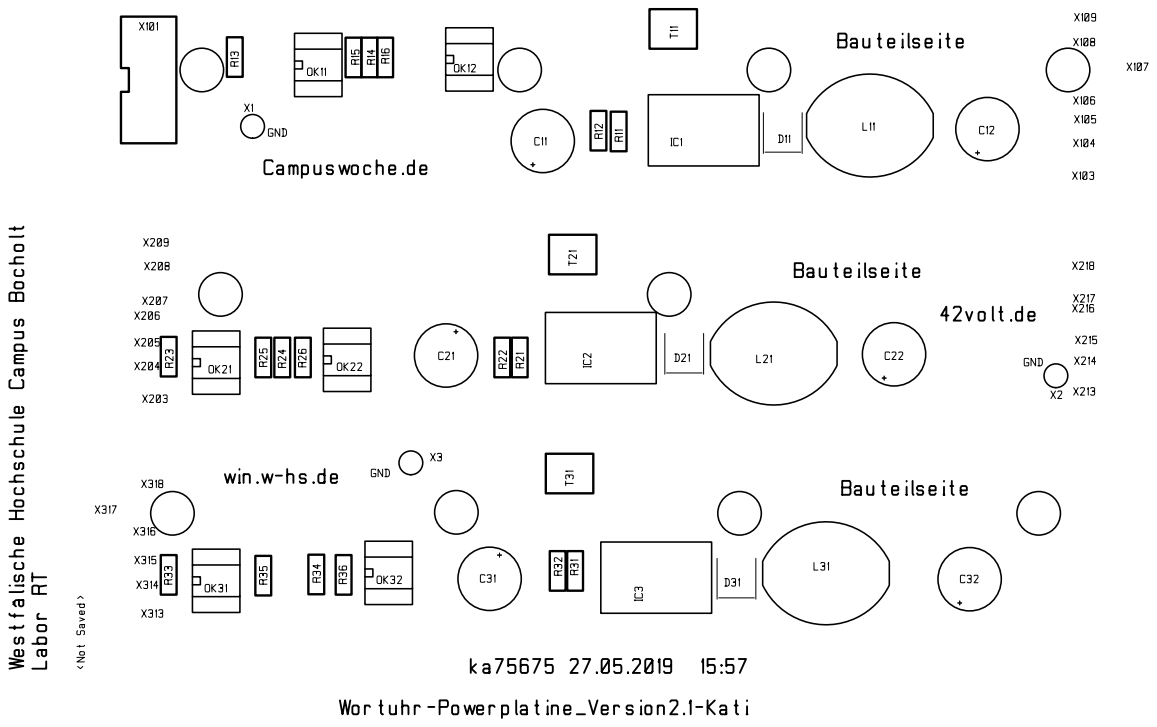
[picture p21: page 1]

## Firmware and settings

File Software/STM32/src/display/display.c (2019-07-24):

/*-------------------------------------------------------------------------------------------------------------------------------------------
 * display.c - routines for LED display 16x18 and 10x11
 *
 * Copyright (c) 2014-2018 Frank Meyer - frank(at)fli4l.de
 *
 * This program is free software; you can redistribute it and/or modify
 * it under the terms of the GNU General Public License as published by
 * the Free Software Foundation; either version 2 of the License, or
 * (at your option) any later version.
 *-------------------------------------------------------------------------------------------------------------------------------------------
 */
#include <string.h>
#include <stdio.h>
#include <stdlib.h>
#include <stdint.h>
#include "wclock24h-config.h"
#include "tables.h"
#include "display.h"
#include "overlay.h"

#include "power.h"
#include "irmp.h"
#include "vars.h"

#include "eeprom.h"
#include "eeprom-data.h"
#include "esp-spiffs.h"
#include "delay.h"
#include "ldr.h"
#include "log.h"
#include "base.h"
#include "main.h"

/*+++++++++++++++++++++++++++++++++++++++++++++++++++++++++++++++++++++++++++++++++++++++++++++++++++++++++++++++++++++++++++++++
HERE IS A SHORT PROGRAM TO CALCULATE THE PWM TABLE:

//-----------------------------------------------------------------------------------------------------------------------------
// pwmtable[i] = floor(maxvalue * ((i / (steps - 1)) ^ (1/gamma))w + 0.5)
//
// See also:
// http://www.mikrocontroller.net/articles/Diskussion:LED-Fading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
// http://www.maxim-ic.com/app-notes/index.mvp/id/3667
//
// Compile it with: cc gamma.c -o gamma -lm
//-----------------------------------------------------------------------------------------------------------------------------

#include <stdio.h>
#include <math.h>

#define STEPS       (64)            // CHANGE HERE
#define PWMBITS     (8)             // CHANGE HERE

// GAMMA:
// 0.5   für punktförmige oder aufblitzende Helligkeiten
// 0.33  für Lichtquellen bei 5° Blickwinkel
// 1/2.2 für diffus strahlende LEDs - entspricht der Gammakorrektur von VGA-Bildschirmen
#define GAMMA       (1/2.2)

int main ()
{
    int     maxvalue;
    double  value;
    int     i;

    maxvalue = (1 << PWMBITS) - 1;

    for (i = 0; i < STEPS; i++)
    {
        value = floor ((double) maxvalue * pow ((double) i / (double) (STEPS - 1), 1/(GAMMA)) + 0.5);
        if (i > 0 && value < 1)
        {
            value = 1;
        }

        printf ("%5.0f", value);

        if (i < STEPS - 1)
        {
            putchar (',');
            putchar (' ');
        }

        if (!((i + 1) % 8))
        {
            putchar ('\n');
        }
    }
}

 *+++++++++++++++++++++++++++++++++++++++++++++++++++++++++++++++++++++++++++++++++++++++++++++++++++++++++++++++++++++++++++++++
 */

/*-------------------------------------------------------------------------------------------------------------------------------------------
 * 8-Bit PWM with 64 different settings:
 *-------------------------------------------------------------------------------------------------------------------------------------------
 */
const uint16_t pwmtable8[MAX_COLOR_STEPS]  =
{
    0,     1,     1,     2,     2,     3,     3,     4,
    4,     5,     5,     6,     7,     8,     9,    11,
   13,    14,    16,    18,    20,    23,    25,    28,
   31,    33,    36,    40,    43,    46,    50,    54,
   57,    61,    66,    70,    74,    79,    84,    89,
   94,    99,   105,   110,   116,   122,   128,   134,
  140,   147,   153,   160,   167,   174,   182,   189,
  197,   205,   213,   221,   229,   238,   246,   255
};

static DSP_COLORS       dimmed_display_colors           = DSP_DARK_RED_COLOR;
static DSP_COLORS       dimmed_ambilight_colors         = DSP_DARK_RED_COLOR;
static DSP_COLORS       dimmed_ambilight_marker_colors  = DSP_CYAN_COLOR;

uint_fast8_t daylight_red[24]   = {  0,  0,  0, 15, 31, 47, 63, 63, 63, 63, 63, 63, 63, 63, 63, 63, 63, 63, 63, 47, 31, 15,  0,  0 };
uint_fast8_t daylight_green[24] = {  0,  0,  0,  0,  0,  0,  0,  0,  0, 15, 31, 47, 63, 47, 31, 15,  0,  0,  0,  0,  0,  0,  0,  0 };
uint_fast8_t daylight_blue[24]  = { 63, 47, 31, 15,  0,  0,  0,  0,  0,  0,  0,  0,  0,  0,  0, 15, 31, 47, 63, 63, 63, 63, 63, 63 };


#define MAX_TICKER_DECELERATION                 16
#define DEFAULT_TICKER_DECELERATION             3

#if WCLOCK24H == 1                                              // faster
#  define ANIMATION_NONE_DEFAULT_DEC            2
#  define ANIMATION_FADE_DEFAULT_DEC            4
#  define ANIMATION_ROLL_DEFAULT_DEC            2
#  define ANIMATION_EXPLODE_DEFAULT_DEC         2
#  define ANIMATION_RANDOM_DEFAULT_DEC          2
#  define ANIMATION_SNAKE_DEFAULT_DEC           2
#  define ANIMATION_TELETYPE_DEFAULT_DEC        4
#  define ANIMATION_CUBE_DEFAULT_DEC            2
#  define ANIMATION_GREEN_MATRIX_DEFAULT_DEC    3
#  define ANIMATION_DROP_DEFAULT_DEC            2
#  define ANIMATION_SQUEEZE_DEFAULT_DEC         4
#  define ANIMATION_FLICKER_DEFAULT_DEC         4
#  define ANIMATION_MATRIX_DEFAULT_DEC          3
#  define ANIMATION_RED_MATRIX_DEFAULT_DEC      3
#else                                                           // slower
#  define ANIMATION_NONE_DEFAULT_DEC            4
#  define ANIMATION_FADE_DEFAULT_DEC            4
#  define ANIMATION_ROLL_DEFAULT_DEC            4
#  define ANIMATION_EXPLODE_DEFAULT_DEC         6
#  define ANIMATION_RANDOM_DEFAULT_DEC          4
#  define ANIMATION_SNAKE_DEFAULT_DEC           4
#  define ANIMATION_TELETYPE_DEFAULT_DEC        4
#  define ANIMATION_CUBE_DEFAULT_DEC            4
#  define ANIMATION_GREEN_MATRIX_DEFAULT_DEC    4
#  define ANIMATION_DROP_DEFAULT_DEC            4
#  define ANIMATION_SQUEEZE_DEFAULT_DEC         4
#  define ANIMATION_FLICKER_DEFAULT_DEC         4
#  define ANIMATION_MATRIX_DEFAULT_DEC          4
#  define ANIMATION_RED_MATRIX_DEFAULT_DEC      4
#endif

static void     display_animation_none (void);
static void     display_animation_fade (void);
static void     display_animation_roll (void);
static void     display_animation_explode (void);
static void     display_animation_random (void);
static void     display_animation_snake (void);
static void     display_animation_teletype (void);
static void     display_animation_cube (void);
static void     display_animation_green_matrix (void);
static void     display_animation_drop (void);
static void     display_animation_squeeze (void);
static void     display_animation_flicker (void);
static void     display_animation_matrix (void);
static void     display_animation_red_matrix (void);

static DISPLAY_ICON                     display_icon_st;

DISPLAY_GLOBALS                         display;

#define CURRENT_STATE                   0x01
#define TARGET_STATE                    0x02
#define NEW_STATE                       0x04
#define CALC_STATE                      0x08

static union
{
    uint8_t                             state[DSP_DISPLAY_LEDS];
    uint8_t                             matrix[WC_ROWS][WC_COLUMNS];
} led;

#define MAX_TICKER_LEN  64

static unsigned char                    ticker_str[MAX_TICKER_LEN + 1];
static uint_fast8_t                     ticker_col = 0;
static unsigned char *                  ticker_ptr = ticker_str;

#define TICKER_DEGREE                   1
#define TICKER_UP_A_UMLAUT              2
#define TICKER_UP_O_UMLAUT              3
#define TICKER_UP_U_UMLAUT              4
#define TICKER_LO_A_UMLAUT              5
#define TICKER_LO_O_UMLAUT              6
#define TICKER_LO_U_UMLAUT              7
#define TICKER_SHARP_S                  8

#if WCLOCK24H == 1

#define TICKER_LINES                    8
#define TICKER_COLS                     8

static const char ticker_font[128][TICKER_LINES] =          //  8x8 font: only 7 Bit ASCII + some special characters
{
    { 0x00, 0x00, 0x00, 0x00, 0x00, 0x00, 0x00, 0x00 },     // 0x00   0
    { 0x3C, 0x42, 0x42, 0x3C, 0x00, 0x00, 0x00, 0x00 },     // 0x01   1 degree
    { 0x24, 0x18, 0x24, 0x42, 0x7e, 0x42, 0x42, 0x00 },     // 0x02   2 A umlaut
    { 0x24, 0x00, 0x3c, 0x42, 0x42, 0x42, 0x3c, 0x00 },     // 0x03   3 O umlaut
    { 0x24, 0x00, 0x42, 0x42, 0x42, 0x42, 0x3c, 0x00 },     // 0x04   4 U umlaut
    { 0x24, 0x18, 0x24, 0x42, 0x7e, 0x42, 0x42, 0x00 },     // 0x05   5 a umlaut
    { 0x24, 0x00, 0x3c, 0x42, 0x42, 0x42, 0x3c, 0x00 },     // 0x06   6 o umlaut
    { 0x24, 0x00, 0x42, 0x42, 0x42, 0x42, 0x3c, 0x00 },     // 0x07   7 u umlaut
    { 0x7C, 0x42, 0x7C, 0x42, 0x7C, 0x40, 0x40, 0x00 },     // 0x08   8 sharp s
    { 0x00, 0x00, 0x00, 0x00, 0x00, 0x00, 0x00, 0x00 },     // 0x09   9
    { 0x00, 0x00, 0x00, 0x00, 0x00, 0x00, 0x00, 0x00 },     // 0x0A  10
    { 0x00, 0x00, 0x00, 0x00, 0x00, 0x00, 0x00, 0x00 },     // 0x0B  11
    { 0x00, 0x00, 0x00, 0x00, 0x00, 0x00, 0x00, 0x00 },     // 0x0C  12
    { 0x00, 0x00, 0x00, 0x00, 0x00, 0x00, 0x00, 0x00 },     // 0x0D  13
    { 0x00, 0x00, 0x00, 0x00, 0x00, 0x00, 0x00, 0x00 },     // 0x0E  14
    { 0x00, 0x00, 0x00, 0x00, 0x00, 0x00, 0x00, 0x00 },     // 0x0F  15
    { 0x00, 0x00, 0x00, 0x00, 0x00, 0x00, 0x00, 0x00 },     // 0x10  16
    { 0x00, 0x00, 0x00, 0x00, 0x00, 0x00, 0x00, 0x00 },     // 0x11  17
    { 0x00, 0x00, 0x00, 0x00, 0x00, 0x00, 0x00, 0x00 },     // 0x12  18
    { 0x00, 0x00, 0x00, 0x00, 0x00, 0x00, 0x00, 0x00 },     // 0x13  19
    { 0x00, 0x00, 0x00, 0x00, 0x00, 0x00, 0x00, 0x00 },     // 0x14  20
    { 0x00, 0x00, 0x00, 0x00, 0x00, 0x00, 0x00, 0x00 },     // 0x15  21
    { 0x00, 0x00, 0x00, 0x00, 0x00, 0x00, 0x00, 0x00 },     // 0x16  22
    { 0x00, 0x00, 0x00, 0x00, 0x00, 0x00, 0x00, 0x00 },     // 0x17  23
    { 0x00, 0x00, 0x00, 0x00, 0x00, 0x00, 0x00, 0x00 },     // 0x18  24
    { 0x00, 0x00, 0x00, 0x00, 0x00, 0x00, 0x00, 0x00 },     // 0x19  25
    { 0x00, 0x00, 0x00, 0x00, 0x00, 0x00, 0x00, 0x00 },     // 0x1A  26
    { 0x00, 0x00, 0x00, 0x00, 0x00, 0x00, 0x00, 0x00 },     // 0x1B  27
    { 0x00, 0x00, 0x00, 0x00, 0x00, 0x00, 0x00, 0x00 },     // 0x1C  28
    { 0x00, 0x00, 0x00, 0x00, 0x00, 0x00, 0x00, 0x00 },     // 0x1D  29
    { 0x00, 0x00, 0x00, 0x00, 0x00, 0x00, 0x00, 0x00 },     // 0x1E  30
    { 0x00, 0x00, 0x00, 0x00, 0x00, 0x00, 0x00, 0x00 },     // 0x1F  31
    { 0x00, 0x00, 0x00, 0x00, 0x00, 0x00, 0x00, 0x00 },     // 0x20  32
    { 0x38, 0x38, 0x38, 0x10, 0x00, 0x38, 0x38, 0x00 },     // 0x21  33 !
    { 0xee, 0xee, 0x44, 0x00, 0x00, 0x00, 0x00, 0x00 },     // 0x22  34 "
    { 0x28, 0x28, 0xfe, 0x28, 0xfe, 0x28, 0x28, 0x00 },     // 0x23  35 #
    { 0x7c, 0x92, 0x90, 0x7c, 0x12, 0x92, 0x7c, 0x00 },     // 0x24  36 $
    { 0xe2, 0xa4, 0xe8, 0x10, 0x2e, 0x4a, 0x8e, 0x00 },     // 0x25  37 %
    { 0x30, 0x48, 0x30, 0x70, 0x8a, 0x84, 0x7a, 0x00 },     // 0x26  38 &
    { 0x38, 0x38, 0x10, 0x20, 0x00, 0x00, 0x00, 0x00 },     // 0x27  39 '
    { 0x18, 0x20, 0x40, 0x40, 0x40, 0x20, 0x18, 0x00 },     // 0x28  40 (
    { 0x30, 0x08, 0x04, 0x04, 0x04, 0x08, 0x30, 0x00 },     // 0x29  41 )
    { 0x00, 0x44, 0x28, 0xee, 0x28, 0x44, 0x00, 0x00 },     // 0x2A  42 *
    { 0x00, 0x10, 0x10, 0x7c, 0x10, 0x10, 0x00, 0x00 },     // 0x2B  43 +
    { 0x00, 0x00, 0x00, 0x38, 0x38, 0x10, 0x20, 0x00 },     // 0x2C  44 ,
    { 0x00, 0x00, 0x00, 0x7c, 0x00, 0x00, 0x00, 0x00 },     // 0x2D  45 -
    { 0x00, 0x00, 0x00, 0x00, 0x38, 0x38, 0x38, 0x00 },     // 0x2E  46 .
    { 0x02, 0x04, 0x08, 0x10, 0x20, 0x40, 0x80, 0x00 },     // 0x2F  47 /
    { 0x38, 0x44, 0xa2, 0x92, 0x8a, 0x44, 0x38, 0x00 },     // 0x30  48 0
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
    { 0x7c, 0x82, 0x82, 0x82, 0x82, 0x82, 0x7c, 0x00 },     // 0x4F  79 O fm: 0xfe -> 0x7c
    { 0xfc, 0x82, 0x82, 0xfc, 0x80, 0x80, 0x80, 0x00 },     // 0x50  80 P
    { 0x7c, 0x82, 0x82, 0x82, 0x8a, 0x84, 0x7a, 0x00 },     // 0x51  81 Q
    { 0xfc, 0x82, 0x82, 0xfc, 0x88, 0x84, 0x82, 0x00 },     // 0x52  82 R
    { 0x7c, 0x82, 0x80, 0x7c, 0x02, 0x82, 0x7c, 0x00 },     // 0x53  83 S
    { 0xfe, 0x10, 0x10, 0x10, 0x10, 0x10, 0x10, 0x00 },     // 0x54  84 T
    { 0x82, 0x82, 0x82, 0x82, 0x82, 0x82, 0x7c, 0x00 },     // 0x55  85 U
    { 0x82, 0x82, 0x82, 0x82, 0x44, 0x28, 0x10, 0x00 },     // 0x56  86 V
    { 0x82, 0x92, 0x92, 0x92, 0x92, 0x92, 0x6c, 0x00 },     // 0x57  87 W
    { 0x82, 0x44, 0x28, 0x10, 0x28, 0x44, 0x82, 0x00 },     // 0x58  88 X
    { 0x82, 0x44, 0x28, 0x10, 0x10, 0x10, 0x10, 0x00 },     // 0x59  89 Y
    { 0xfe, 0x04, 0x08, 0x10, 0x20, 0x40, 0xfe, 0x00 },     // 0x5A  90 Z
    { 0x7c, 0x40, 0x40, 0x40, 0x40, 0x40, 0x7c, 0x00 },     // 0x5B  91 [
    { 0x80, 0x40, 0x20, 0x10, 0x08, 0x04, 0x02, 0x00 },     // 0x5C  92 backslash
    { 0x7c, 0x04, 0x04, 0x04, 0x04, 0x04, 0x7c, 0x00 },     // 0x5D  93 ]
    { 0x10, 0x28, 0x44, 0x00, 0x00, 0x00, 0x00, 0x00 },     // 0x5E  94 ^
    { 0x00, 0x00, 0x00, 0x00, 0x00, 0x00, 0xfe, 0x00 },     // 0x5F  95 _
    { 0x38, 0x38, 0x10, 0x08, 0x00, 0x00, 0x00, 0x00 },     // 0x60  96 `
    { 0x00, 0x18, 0x24, 0x42, 0x7e, 0x42, 0x42, 0x00 },     // 0x61  97 a
    { 0x00, 0x7c, 0x42, 0x7c, 0x42, 0x42, 0x7c, 0x00 },     // 0x62  98 b
    { 0x00, 0x3c, 0x42, 0x40, 0x40, 0x42, 0x3c, 0x00 },     // 0x63  99 c
    { 0x00, 0x7c, 0x42, 0x42, 0x42, 0x42, 0x7c, 0x00 },     // 0x64 100 d
    { 0x00, 0x7e, 0x40, 0x7c, 0x40, 0x40, 0x7e, 0x00 },     // 0x65 101 e
    { 0x00, 0x7e, 0x40, 0x7c, 0x40, 0x40, 0x40, 0x00 },     // 0x66 102 f
    { 0x00, 0x3c, 0x42, 0x40, 0x4e, 0x42, 0x3c, 0x00 },     // 0x67 103 g
    { 0x00, 0x42, 0x42, 0x7e, 0x42, 0x42, 0x42, 0x00 },     // 0x68 104 h
    { 0x00, 0x08, 0x08, 0x08, 0x08, 0x08, 0x08, 0x00 },     // 0x69 105 i
    { 0x00, 0x02, 0x02, 0x02, 0x02, 0x42, 0x3c, 0x00 },     // 0x6A 106 j
    { 0x00, 0x42, 0x44, 0x78, 0x48, 0x44, 0x42, 0x00 },     // 0x6B 107 k
    { 0x00, 0x40, 0x40, 0x40, 0x40, 0x40, 0x7e, 0x00 },     // 0x6C 108 l
    { 0x00, 0x42, 0x66, 0x5a, 0x42, 0x42, 0x42, 0x00 },     // 0x6D 109 m
    { 0x00, 0x42, 0x62, 0x52, 0x4a, 0x46, 0x42, 0x00 },     // 0x6E 110 n
    { 0x00, 0x3c, 0x42, 0x42, 0x42, 0x42, 0x3c, 0x00 },     // 0x6F 111 o
    { 0x00, 0x7c, 0x42, 0x42, 0x7c, 0x40, 0x40, 0x00 },     // 0x70 112 p
    { 0x00, 0x3c, 0x42, 0x42, 0x4a, 0x44, 0x3a, 0x00 },     // 0x71 113 q
    { 0x00, 0x7c, 0x42, 0x42, 0x7c, 0x44, 0x42, 0x00 },     // 0x72 114 r
    { 0x00, 0x3c, 0x40, 0x3c, 0x02, 0x42, 0x3c, 0x00 },     // 0x73 115 s
    { 0x00, 0x3e, 0x08, 0x08, 0x08, 0x08, 0x08, 0x00 },     // 0x74 116 t
    { 0x00, 0x42, 0x42, 0x42, 0x42, 0x42, 0x3c, 0x00 },     // 0x75 117 u
    { 0x00, 0x42, 0x42, 0x42, 0x42, 0x24, 0x18, 0x00 },     // 0x76 118 v
    { 0x00, 0x42, 0x42, 0x42, 0x5a, 0x66, 0x42, 0x00 },     // 0x77 119 w
    { 0x00, 0x42, 0x24, 0x18, 0x18, 0x24, 0x42, 0x00 },     // 0x78 120 x
    { 0x00, 0x22, 0x14, 0x08, 0x08, 0x08, 0x08, 0x00 },     // 0x79 121 y
    { 0x00, 0x7e, 0x04, 0x08, 0x10, 0x20, 0x7e, 0x00 },     // 0x7A 122 z
    { 0x38, 0x40, 0x40, 0xc0, 0x40, 0x40, 0x38, 0x00 },     // 0x7B 123 {
    { 0x10, 0x10, 0x10, 0x00, 0x10, 0x10, 0x10, 0x00 },     // 0x7C 124 |
    { 0x38, 0x04, 0x04, 0x06, 0x04, 0x04, 0x38, 0x00 },     // 0x7D 125 }
    { 0x60, 0x92, 0x0c, 0x00, 0x00, 0x00, 0x00, 0x00 },     // 0x7E 126 ~
    { 0x00, 0x00, 0x00, 0x00, 0x00, 0x00, 0x00, 0x00 }      // 0x7F 127 DEL
};

#else // 12h:

#define TICKER_LINES                8
#define TICKER_COLS                 5
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

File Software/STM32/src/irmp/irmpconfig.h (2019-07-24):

/*---------------------------------------------------------------------------------------------------------------------------------------------------
 * irmpconfig.h
 *
 * DO NOT INCLUDE THIS FILE, WILL BE INCLUDED BY IRMP.H!
 *
 * Copyright (c) 2009-2018 Frank Meyer - frank(at)fli4l.de
 * Extensions for PIC 12F1820 W.Strobl 2014-07-20
 *
 * $Id: irmpconfig.h,v 1.123 2015/01/19 10:54:37 fm Exp $
 *
 * This program is free software; you can redistribute it and/or modify
 * it under the terms of the GNU General Public License as published by
 * the Free Software Foundation; either version 2 of the License, or
 * (at your option) any later version.
 *---------------------------------------------------------------------------------------------------------------------------------------------------
 */

#ifndef _IRMPCONFIG_H_
#define _IRMPCONFIG_H_

#ifndef _IRMP_H_
#  error please include only irmp.h, not irmpconfig.h
#endif

/*---------------------------------------------------------------------------------------------------------------------------------------------------
 * Change F_INTERRUPTS if you change the number of interrupts per second,
 * Normally, F_INTERRUPTS should be in the range from 10000 to 15000, typical is 15000
 * A value above 15000 costs additional program space, absolute maximum value is 20000.
 * On PIC with XC8/C18 Compiler, use 15151 as the correct value.
 *---------------------------------------------------------------------------------------------------------------------------------------------------
 */
#ifndef F_INTERRUPTS
#  define F_INTERRUPTS                          15000   // interrupts per second, min: 10000, max: 20000, typ: 15000
#endif

/*---------------------------------------------------------------------------------------------------------------------------------------------------
 * Change settings from 1 to 0 if you want to disable one or more decoders.
 * This saves program space.
 *
 * 1 enable  decoder
 * 0 disable decoder
 *
 * The standard decoders are enabled per default.
 * Less common protocols are disabled here, you need to enable them manually.
 *
 * If you want to use FDC or RCCAR simultaneous with RC5 protocol, additional program space is required.
 * If you don't need RC5 when using FDC/RCCAR, you should disable RC5.
 * You cannot enable both DENON and RUWIDO, only enable one of them.
 *---------------------------------------------------------------------------------------------------------------------------------------------------
 */

// typical protocols, disable here!             Enable  Remarks                 F_INTERRUPTS            Program Space
#define IRMP_SUPPORT_SIRCS_PROTOCOL             1       // Sony SIRCS           >= 10000                 ~150 bytes
#define IRMP_SUPPORT_NEC_PROTOCOL               1       // NEC + APPLE          >= 10000                 ~300 bytes
#define IRMP_SUPPORT_SAMSUNG_PROTOCOL           1       // Samsung + Samsg32    >= 10000                 ~300 bytes
#define IRMP_SUPPORT_KASEIKYO_PROTOCOL          1       // Kaseikyo             >= 10000                 ~250 bytes

// more protocols, enable here!                 Enable  Remarks                 F_INTERRUPTS            Program Space
#define IRMP_SUPPORT_JVC_PROTOCOL               0       // JVC                  >= 10000                 ~150 bytes
#define IRMP_SUPPORT_NEC16_PROTOCOL             0       // NEC16                >= 10000                 ~100 bytes
#define IRMP_SUPPORT_NEC42_PROTOCOL             0       // NEC42                >= 10000                 ~300 bytes
#define IRMP_SUPPORT_MATSUSHITA_PROTOCOL        0       // Matsushita           >= 10000                  ~50 bytes
#define IRMP_SUPPORT_DENON_PROTOCOL             0       // DENON, Sharp         >= 10000                 ~250 bytes
#define IRMP_SUPPORT_RC5_PROTOCOL               0       // RC5                  >= 10000                 ~250 bytes
#define IRMP_SUPPORT_RC6_PROTOCOL               0       // RC6 & RC6A           >= 10000                 ~250 bytes
#define IRMP_SUPPORT_IR60_PROTOCOL              0       // IR60 (SDA2008)       >= 10000                 ~300 bytes
#define IRMP_SUPPORT_GRUNDIG_PROTOCOL           0       // Grundig              >= 10000                 ~300 bytes
#define IRMP_SUPPORT_SIEMENS_PROTOCOL           0       // Siemens Gigaset      >= 15000                 ~550 bytes
#define IRMP_SUPPORT_NOKIA_PROTOCOL             0       // Nokia                >= 10000                 ~300 bytes
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

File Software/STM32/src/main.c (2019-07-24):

/*-------------------------------------------------------------------------------------------------------------------------------------------
 * main.c - main routines of wclock24h
 *
 * Copyright (c) 2014-2018 Frank Meyer - frank(at)fli4l.de
 *
 * System Clocks configured on STM32F103 Mini development board:
 *
 *    External 8MHz crystal
 *    SYSCLK:       72MHz ((HSE_VALUE / HSE_Prediv) * PLL_Mul) = ((8MHz / 1) * 9)  = 72MHz
 *    AHB clock:    72MHz (AHB  Prescaler = 1)
 *    APB1 clock:   36MHz (APB1 Prescaler = 2)
 *    APB2 clock:   72MHz (APB2 Prescaler = 1)
 *    Timer clock:  72MHz (APB1 Prescaler = 2, Timer Multiplier 2)
 *
 * System Clocks configured on STM32F401 Nucleo Board (see changes in system_stm32f4xx.c):
 *
 *    External 8MHz crystal
 *    Main clock:   84MHz ((HSE_VALUE / PLL_M) * PLL_N) / PLL_P = ((8MHz / 4) * 84) / 2 = 84MHz
 *    AHB clock:    84MHz (AHB  Prescaler = 1)
 *    APB1 clock:   42MHz (APB1 Prescaler = 2)
 *    APB2 clock:   84MHz (APB2 Prescaler = 1)
 *    Timer clock:  84MHz
 *
 * System Clocks configured on STM32F411 Nucleo Board (see changes in system_stm32f4xx.c):
 *
 *    External 8MHz crystal
 *    Main clock:   100MHz ((HSE_VALUE / PLL_M) * PLL_N) / PLL_P = ((8MHz / 4) * 100) / 2 = 100MHz
 *    AHB clock:    100MHz (AHB  Prescaler = 1)
 *    APB1 clock:    50MHz (APB1 Prescaler = 2)
 *    APB2 clock:   100MHz (APB2 Prescaler = 1)
 *    Timer clock:  100MHz
 *
 * System Clocks configured on STM32F446 Nucleo Board (see changes in system_stm32f4xx.c):
 *
 *    External 8MHz crystal
 *    Main clock:   180MHz ((HSE_VALUE / PLL_M) * PLL_N) / PLL_P = ((8MHz / 4) * 180) / 2 = 180MHz
 *    AHB clock:    180MHz (AHB  Prescaler = 1)
 *    APB1 clock:    45MHz (APB1 Prescaler = 4)
 *    APB2 clock:    90MHz (APB2 Prescaler = 2)
 *    Timer clock:  180MHz
 *
 * On STM32F4xx Nucleo Board, make sure that
 *
 *    - SB54 and SB55 are OFF
 *    - SB16 and SB50 are OFF
 *    - R35 and R37 are soldered (0R or simple wire)
 *    - C33 and C34 are soldered with 22pF capacitors
 *    - X3 is soldered with 8MHz crystal
 *
 * Internal devices used:
 *
 *    +-------------------------+---------------------------------------+-----------------------------------+-------------------------------+
 *    | Device                  | STM32F4x1 Nucleo                      | STM32F103C8T6                     | Remarks                       |
 *    +-------------------------+---------------------------------------+-----------------------------------+-------------------------------+
 *    | User button             | GPIO:          PC13                   | GPIO:      PA6                    |                               |
 *    | Board LED               | GPIO:          PA5                    | GPIO:      PC13                   |                               |
 *    +-------------------------+---------------------------------------+-----------------------------------+-------------------------------+
 *
 * External devices:
 *
 *    +-------------------------+---------------------------------------+-----------------------------------+-------------------------------+
 *    | Device                  | STM32F4x1 Nucleo                      | STM32F103C8T6                     | Remarks                       |
 *    +-------------------------+---------------------------------------+-----------------------------------+-------------------------------+
 *    | TSOP31238 (IRMP)        | GPIO:          PC10                   | GPIO:      PB3                    |                               |
 *    | DS18xx (OneWire)        | GPIO:          PD2                    | GPIO:      PB5                    |                               |
 *    | Logger (Nucleo: USB)    | USART2:        TX=PA2  RX=PA3         | USART1:    TX=PA9  RX=PA10        |                               |
 *    | WPS button              | GPIO:          PC5                    | GPIO:      PA7                    |                               |
 *    | ESP8266 USART           | USART6:        TX=PA11 RX=PA12        | USART2:    TX=PA2  RX=PA3         |                               |
 *    | ESP8266 RST/CH_PD       | GPIO:          RST=PA7 CH_PD=PA6      | GPIO:      RST=PA0 CH_PD=PA1      |                               |
 *    | ESP8266 GPIO0           | GPIO:          FLASH=PA4              | GPIO:      FLASH=PA4              |                               |
 *    | ESP8266 GPIO13/GPIO15   | USART1:        GPIO13=PA9 GPIO15=PA10 | USART1:    GPIO13=PA9 GPIO15=PA10 | Only in STM32 bootloader mode |
 *    | ESP8266 GPIO14          | GPIO:          GPIO14=RESET           | GPIO:      GPIO14=RESET           |                               |
 *    | ESP8266 GPIO4           | GPIO:          GPIO4=BOOT0            | GPIO:      GPIO4=BOOT0            |                               |
 *    | DCF77                   | GPIO:          DATA=PC11 PON=PC12     | GPIO:      DATA=PB8  PON=PB9      |                               |
 *    | I2C DS3231 & EEPROM     | I2C3:          SCL=PA8 SDA=PC9        | I2C1:      SCL=PB6 SDA=PB7        |                               |
 *    | LDR                     | ADC:           ADC1_IN14=PC4          | ADC:       ADC12_IN5=PA5          |                               |
 *    | WS2812 / SK6812         | TIM3/DMA1:     PC6                    | TIM1/DMA1: PA8                    |                               |
 *    | APA102                  | SPI2/DMA1:     SCK=PB13 MOSI=PB15     | SPI2/DMA1: SCK=PB13 MOSI=PB15     |                               |
 *    | Power switch            | GPIO:          PC8                    | GPIO:      PB0                    |                               |
 *    | Beeper                  | PWM:           PB1 TIM3/CH4           | PWM:       PB1 TIM3/CH4           |                               |
 *    | DFPlayer                | USART1 (ALT1): TX=PB6  RX=PB7         | USART3:    TX=PB10  RX=PB11       |                               |
 *    +-------------------------+---------------------------------------+-----------------------------------+-------------------------------+
 *    | Free Port A             | PA0 PA1 PA15                          | PA11 PA12 PA15                    |                               |
 *    | Free Port B             | PB0 PB2 PB4  PB5 PB12 PB14            | PB4  PB12 PB14                    |                               |
 *    | Free Port C             | PC3 PC7 PC14 PC15                     | PC14 PC15                         |                               |
 *    +-------------------------+---------------------------------------+-----------------------------------+-------------------------------+
 *
 * Timers:
 *
 *    +-------------------------+---------------------------------------+-----------------------------------+-------------------------------+
 *    | Device                  | STM32F4x1 Nucleo                      | STM32F103C8T6                     | Remarks                       |
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

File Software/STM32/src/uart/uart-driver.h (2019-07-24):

/*---------------------------------------------------------------------------------------------------------------------------------------------------
 * uart-driver.h - UART driver routines for STM32F4XX or STM32F10X
 *
 * Copyright (c) 2015-2018 Frank Meyer - frank(at)fli4l.de
 *
 * example of usage:
 *
 * #define UART_PREFIX         log                      // prefix for all USART functions, e.g. log_uart_puts()
 * #define UART_NUMBER         3                        // UART number on STM32F1xx (1-3 for STM32F1xx, 1-6 for STM32F4xx)
 * #define UART_ALTERNATE      0                        // ALTERNATE pin number, see below for possible values
 *
 * #define UART_TXBUFLEN       64                       // ringbuffer size for UART TX
 * #define UART_RXBUFLEN       64                       // ringbuffer size for UART RX
 *
 * include "uart-driver.h"                              // at least include this file
 *
 * Possible UARTs of STM32F10x:
 *           ALTERNATE=0    ALTERNATE=1    ALTERNATE=2
 *  +--------------------------------------------------+
 *  | UART | TX   | RX   || TX   | RX   || TX   | RX   |
 *  |======|======|======||======|======||======|======|
 *  | 1    | PA9  | PA10 || PB6  | PB7  ||      |      |
 *  | 2    | PA2  | PA3  || PD5  | PD6  ||      |      |
 *  | 3    | PB10 | PB11 || PC10 | PC11 || PD8  | PD9  |
 *  +--------------------------------------------------+
 *
 * Possible UARTs of STM32F4xx Nucleo:
 *           ALTERNATE=0    ALTERNATE=1    ALTERNATE=2
 *  +--------------------------------------------------+
 *  | UART | TX   | RX   || TX   | RX   || TX   | RX   |
 *  |======|======|======||======|======||======|======|
 *  | 1    | PA9  | PA10 || PB6  | PB7  ||      |      |
 *  | 2    | PA2  | PA3  || PD5  | PD6  ||      |      |
 *  | 6    | PC6  | PC7  || PA11 | PA12 ||      |      |
 *  +--------------------------------------------------+
 *
 * Possible UARTs of STM32F407:
 *           ALTERNATE=0    ALTERNATE=1    ALTERNATE=2
 *  +--------------------------------------------------+
 *  | UART | TX   | RX   || TX   | RX   || TX   | RX   |
 *  |======|======|======||======|======||======|======|
 *  | 1    | PA9  | PA10 || PB6  | PB7  ||      |      |
 *  | 2    | PA2  | PA3  || PD5  | PD6  ||      |      |
 *  | 3    | PB10 | PB11 || PC10 | PC11 || PD8  | PD9  |
 *  | 4    | PA0  | PA1  || PC10 | PC11 ||      |      |
 *  | 5    | PC12 | PD2  ||      |      ||      |      |
 *  | 6    | PC6  | PC7  || PG14 | PG9  ||      |      |
 *  +--------------------------------------------------+
 *
 * This program is free software; you can redistribute it and/or modify
 * it under the terms of the GNU General Public License as published by
 * the Free Software Foundation; either version 2 of the License, or
 * (at your option) any later version.
 *---------------------------------------------------------------------------------------------------------------------------------------------------
 */

#include <stdio.h>
#include <stdlib.h>
#include <string.h>

#if (defined STM32F4XX)
#include "stm32f4xx.h"
#include "stm32f4xx_gpio.h"
#include "stm32f4xx_usart.h"
#include "stm32f4xx_rcc.h"
#include "misc.h"

#elif (defined STM32F10X)
#include "stm32f10x.h"
#include "stm32f10x_gpio.h"
#include "stm32f10x_usart.h"
#include "stm32f10x_rcc.h"
#include "misc.h"

#endif

#include "uart.h"

static volatile uint8_t             uart_txbuf[UART_TXBUFLEN];                  // tx ringbuffer
static volatile uint_fast16_t       uart_txsize = 0;                            // tx size
static volatile uint8_t             uart_rxbuf[UART_RXBUFLEN];                  // rx ringbuffer
static volatile uint_fast16_t       uart_rxsize = 0;                            // rx size
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

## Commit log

2018-03-25 - add option to define vertical led layout to display-config.h - implement vertical led layout in display.c (untested) - correct column and row number in tables.h
    [display-config.h, display.c]
2018-03-27 - fix compile error
    [display.c]
2018-04-22 - remove status led
2018-04-22 - try to fix wrong vertical output made x and y directions the same as normal display
    [display.c]
2018-07-30 set GPIO Pins for our new controller board
2018-07-31 change power-on to step by step mode with delay
2018-08-02 add pcb, schematics and pictures
2018-08-03 fix power up delay
    [power.c]
2018-08-09 change default config to WS2812_GRB_LED to fix led colours
    [display-config.h]
2018-11-29 add Gitter Ordner
    [Gitter.dxf, Gitter_Horizontal.dxf, Gitter_Vertikal.dxf]
2019-01-03 -sort power pins -turn off leds after enable of each power pin
2019-01-03 -turn power on after led init -add NOIR mode for builds without ir-led
2019-07-18 -show red cross on startup -show startup steps with red leds in the left column -show moving red led if esp is not (yet) connected -if access point name has "$$$$$$", it is replaced with ESP device id
    [ESP-WordClock.ino, main.c]
2019-07-23 -fix stm32 compile warnings
    [main.c]
2025-07-30 add backwards option for leds in display-config.h
